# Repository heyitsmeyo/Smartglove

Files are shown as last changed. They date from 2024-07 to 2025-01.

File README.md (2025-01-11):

# Smartglove
The project is about a smart glove that translates ASL (American sign language ) to text and speech using a machine learning model based on random forest algorithms , the model is deployed on a raspberry pi 4 model B  , the glove comes with a esp32 , five fkex sensors and a module that integrates both gyroscope and accelerometer (MPU6050) 

The dataset used in this project can be found here : https://figshare.com/articles/dataset/ASL-Sensor-Dataglove-Dataset_zip/20031017?file=35776586

Screenshot_20240523_001544_Gallery (1)

# PCBDesign : 

pcb

# pcbSchematic :



# if you like the project , you can donate us for more : 

    https://ko-fi.com/heyitsmeyo

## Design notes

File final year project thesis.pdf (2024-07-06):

éJ

J

.ªË@

éJ

£@Q
®Öß

YË@
éK

Q

K@ Qm.

Ì'@
éK

PñêÒm.

Ì'@

Peoples Democratic Republic of Algeria ù

ÒÊªË@ IjJ

Ë@ ð ú

ÍAªË@ Õæ

Êª

JË@
èP@ Pð

Ministry of Higher Education and scientific research

éÓY
®
JÖÏ@ HAJ
k.ñËñ

Jº
JÊË AJ

ÊªË@
éJ

J£ñË@
éPYÖÏ@

National High School of Advanced Technology Department of Electrical Engineering and Industrial Computer Science

### Final Year Project to Obtain the Diploma of

### Engineering

### Field:

### Electronics

### Specialty:

### Embedded Systems

### Subject:

## A Smart Glove Empowered by AI embedded on a Raspberry

Pi

### Realized by

### Benbrahim Tarek

Examination Committee:
Chair | Zellat Khadidja | ENSTA
Supervisor | Bougherirah Hamida USD Blida
Co-Supervisor | Habani Lamia | ENSTA
Examiner | Bouchama Samira | ENSTA
Examiner | Kheira Lakhdari | ENSTA

Algiers, The 26/06/2024

### Academic year 2023 - 2024

Abstract
This thesis presents the development of a smart glove system designed to translate ASL gestures into text and speech. The system uses a combination of flex sensors for finger movement detection, a module that combines accelerometer and a gyroscope for hand gesture capture, and a microcontroller for data processing. Data from all the sensors modules is acquired using an esp32, while the Raspberry Pi 4 is used for executing a machine learning model based on Random Forest algorithms. This model is trained with a dataset to recognize ASL gestures and convert them into text which is then synthesized into speech using a TTS module. That glove aims to help the deaf community to interact easily with the other categories of the society.Initial testings showed successful results,future work will focus on improving the device’s capabilities with other sign languages.
Keywords: machine learning ,microcontroller , Random forest , wireless communication , smart glove , sign language.
R´esum´e:
Cette th`ese pr´esente un gant intelligent traduisant les gestes ASL en texte et parole. Il utilise des capteurs de fl´exions , un acc´el´erom`etre, un gyroscope pour d´etecter les mouvements, et un microcontrˆoleur pour le traitement des donn´ees. Un mod`ele d’apprentissage automatique sur Raspberry Pi 4 reconnaˆıt et convertit les gestes en texte, puis en parole avec un module TTS. Le gant aide la communaut´e sourde `a interagir plus facilement, avec des r´esultats positifs lors des premiers tests. Mots-cl´es: apprentissage automatique, microcontrˆoleur, forˆet al´eatoire, communication sans fil, gant intelligent, langue des signes.

:

jÊÓ

úÍ@

éJ

ºK
QÓ

B@
èPA B
@
é

ªË
éÔg

Q

Ë ÕÔÓ ú

»
X

PA
®
¯ ÐA ¢
QK

ñ¢
ékðQ£

B@ è
Yë ÐY
®
K
èYgðð , ©K.

A

B@
é»Qk á«

ºÊË

é

KQÖÏ@ PAª

B@
è

Qêk.

@ áÓ A

m

'
QÓ ÐA ¢

JË@ ÐY
j
J

.ÐC¿ð

ém

Ì'AªÖÏ

é
®J
¯X Õºm
èYgðð , YJ

Ë@ H@ZAÖ
ß

@

A
®
JËB H.

ñºðQ
m

Ì'@ð ¨PA
Ë@ AJ
®Ó á

K

. ©Òm.

, esp32
èYgð Ð@Y
j
JAK

PAª

B@ H@Ygð ©J
Ôg

áÓ HA
KAJ
J

Ë@ úÎ« ÈñmÌ'@ Õ
æK

.HA
KAJ
J

Ë@

éK

A

ªË@ HAJ
Ó

PP@ñ k úÎ« YÒ
JªK

ú

Í

@ Õ
Îª
K h.
XñÖ

ß
YJ

®

J

JË Raspberry Pi 4 PAêk.

Ð@Y
j

J@ Õ
æK

AÒ
J

K
èPA B
@
é

ªË H@ZAÖ
ß

@
úÎ«

¬Qª
JÊË HA
KAJ
K
é«ñÒm.

× Ð@Y
j
JAK
. h.

XñÒ

JË@ @
Yë I.

K

PY
K Õ
æK

éJ

K@ñªË@

úÍ@

JË@ ÉK
ñm
èYgð Ð@Y
j
JAK

ÐC¿ úÍ@
½Ë
X YªK

é

®J

Ëñ
K Õ
æK

úÍ@
AêÊK

ñm

ð
éJ

ºK
QÓ

B@

áÓ øQ

k

B@ HA
J

®Ë@ ©Ó
éËñîD. É«A
®

JË@ úÎ« ÕæË@ ©Ò
Jm

×

èY«AÓ úÍ@
PA
®
®Ë@ @
Yë

¬YîE

.ÐC¿

á

m

úÎ«
ú

ÎJ
®
JÖÏ@ ÉÒªË@ Q»Q
ð ,
émk

A
K l .
A
J

K

éJ

Ëð

B@ H@PAJ
J

kB@ HQê

£

@ Y
¯ð , ©Ò
Jj.

ÖÏ@

.øQ

k

B@
èPA B

@ HA
ªË ©Ó PAêm.

Ì'@ H@PY

¯

HBA

B@ ,
éJ

K@ñªË@

éK

A

ªË@ HAJ
Ó

PP@ñ k ,

J
¯YË@ Õºj

JÖÏ@ ,
éË
B@ ÕÎª
K :
éJ

kA
J

®ÖÏ@ HAÒÊ¾Ë@

èPA B
@
é

ªË , ú

»
YË@ PA
®

®Ë@ ,
éJ

ºÊCË@

# Acknowledgments

### I would like to extend our heartfelt gratitude to the Almighty God, the All-Powerful and Merciful, who gave us the strength and dedication to

complete this work.

### I deeply appreciate the guidance and dedication of my co-supervisor Mme.Habani and my supervisor Mme.Bougherira, who generously

shared their expertise, time, and effort towards achieving this great work.

### Many thanks to the jury members for their interest in our work and

their willingness to evaluate it.

### I am also grateful to my family members, whose unwavering support and assistance have been instrumental in my journey towards the com-

pletion of this endeavor.

# Dedication

These first words are dedicated to my beloved parents , my mother , my father. These words are full of deep feelings that i wanna write for you , you both gave me support , energy and the zeal to be what I am now.

My mother , your priceless contribution to me is what I can’t forget , your words , your sacrifices to create the current version of me are unforgettable , May Allah bless you and keep you safe for our family , your absence is what i can’t think about.

The father , the power of your words tell the amount of wisdom you have , your strength , your confidence taught me a lot to face this life tall and to never think about giving up. May Allah bless you too.

Other feelings expressed to my sisters , my little brother , your company is and still a priceless journey.

To my dear friends , getting to know you wasn’t a coincidence , it was a lesson , a historical event that i can’t lose off my memories , May Allah keep us together and forever

# Table of contents

1 State of the Art | 2
2 Embedded sign language to speech synthesizer design | 16

I

3 Results and implementation of the smart glove | 29

II

# List of Figures

1.1 Hadeel Ayoub | | 4
1.2 Brightsign smart glove | | 4
1.3 supervised learning | | 4
1.4 unsupervised learning | | 4
1.5 Neural Network | | 5
1.6 Support Vector Machine | | 6
1.7 Random Forest | | 6
1.8 Sign language common words | | 7
1.9 American sign language alphabet | | 7
1.10 Raspberry Pi & Arduino Uno | | 8
1.11 Raspberry pi 4 model B | | 9
1.12 Raspberry pi 4 model B Pinout | | 9
1.13 ESP32 Wroom S3 | | 10
1.14 Esp32 Wroom S3 pinout | | 11
1.15 flex sensor 2.2 inch | | 11
1.16 MPU6050 (accelerometer & gyroscope) | | 12
1.17 STREAM System | | 13
1.18 Algeria-Korea partnership certificate | | 13
1.19 PCB Production uni | | 14
1.20 PCB Production uni | | 14
1.21 PCB Production uni | | 14
1.22 PCB Production uni | | 14
2.1 System block diagram | | 17
2.2 Functional flowchart | | 18
2.3 Flex sensor functionality | | 19
2.4 Different bending angles of flex sensor | | 19
2.5 Flex sensor wiring system | | 20
2.6 Flex sensor’s Polarities | | 20
2.7 Wiring Diagram of Flex Sensors to ESP32 | | 20
2.8 Flex sensors wiring schematic | | 20

III

2.9 MPU6050 Axis | | 21
2.10 Wiring Diagram of MPU6050 to ESP32 | | 21
2.11 Esp32-Raspberry pi 4 wireless communication diagram | | 22
2.12 Voting Mechanism in Ensemble Learning for Prediction | | 24
2.13 Random Subset Selection and Classification with Decision Trees . . . . | 24
2.14 Bootstrapping and Aggregation in Random Forests | | 24
2.15 Random forests data bootstrapping | | 24
2.16 Enter Caption | | 26
3.1 Google Colab | | 30
3.2 EasyEda | | 31
3.3 Raspberry pi 4 Linux Desktop | | 32
3.4 RealVnc Viewer | | 32
3.5 Smart glove’s Schematic | | 33
3.6 EasyEda PCB Design | | 34
3.7 PCB Design result | | 34
3.8 3D Top view of Double-Sided PCB Prototype | | 35
3.9 3D bottom View of Double-Sided PCB Prototype | | 35
3.10 UV Exposure After Applying Solder Mask | | 36
3.11 Top View of Double-Sided PCB Prototype | | 36
3.12 Bottom View of Double-Sided PCB Prototype | | 36
3.13 Smart Glove | | | 37
3.14 Flex sensors Calibration code | | 38
3.15 Flex sensors calibration results | | 39
3.16 MPU6050 Calibration process | | 39
3.17 ESP32 WI-Fi connection code | | 40
3.18 Sensors data processing code | | | 40
3.19 Python Code for data reception | | 41
3.20 Sensors data reception results | | 41
3.21 Machine learning Training Process | | 42
3.22 Python code for merging dataset | | 43
3.23 Python code for cleaning dataset | | 43
3.24 Python code for eliminating unnecessary dataset | | 43
3.25 Python code for data normalisation | | 45
3.26 Python Code for Splitting Dataset into Training and Testing Sets . . . | 45
3.27 Random forests classifier python code | | 45
3.28 Python code for generating predictions on Test data | | | 46
3.29 Alphabet Sign language Confusion Matrix (99% model accuracy) . . . | 47
3.30 Sign language expressions Confusion Matrix(98% model accuracy) . . . | 48

IV

3.31 Testing and training accuracy for different number of trees (99% model
accuracy) | | 49
3.32 OOB Score for different number of trees(99% model accuracy) | | 49
3.33 Alphabet sign language ROC curve(99% model accuracy) | | 50
3.34 Alphabet Sign language Confusion Matrix (82% accuracy) | | 52
3.35 Alphabet sign language ROC curve(82% accuracy) | | 53
3.36 Testing and training accuracy for different number of trees(82% accuracy) 54
3.37 OOB Score for different number of trees(82% model accuracy) | | 54
3.38 Enter Caption | | 55
3.39 Testing and training accuracy with classifier’s changed parameters . . . | 57
3.40 Testing and training accuracy with classifier’s default parameters . . . | 57
3.41 letter A in sign language | | 58
3.42 correlation plot of the letter A | | | 58
3.43 letter S in sign language | | 58
3.44 correlation plot of the letter S | | 58
3.45 Decision Tree plot (82% accuracy) | | 59
3.46 Decision Tree plot (99% accuracy | | 60
3.47 Python Code for Dumping machine learning model | | 64
3.48 Python Code for loading machine learning model | | 64

V

# List of Tables

1.1 Literrature survey | | 3
1.2 Raspberry pi Vs Arduino Uno | | | 8
2.1 Dataset sample | | 27
3.1 Dataset pre-processing results | | 44
3.2 sign language expressions Classification report | | 62
3.3 sign language alphabet Classification report | | 63

VI

# List of Abbreviations

1. ADC: Analog to Digital Converter
2. ANN: Artificial Neural Network
3. AUC: Area under the ROC Curve
4. ASL: American Sign Language
5. IDE: Integrated Development Environment
6. I2C: Inter-Integrated Circuit
7. OOB: Out Of Bag
8. PCB: Printed Circuit Board
9. RF: Random Forest
10. ROC: Receiver Operating Characteristic
11. SVM: Support Vector Machine
12. TN: True Negative
13. TP: True Positive
14. VNC: Virtual Network Computing

VII

## General Introduction

The ability to communicate effectively is fundamental to human interaction. However, for individuals who are deaf, spoken language and written text may not be accessible.ASL is a visual language used by many in the deaf community, but its understanding and interpretation by those who are unfamiliar with it can be a challenge. This issue shows the importance of finding new solutions.Motivated by this need, our project consists of the development of a smart glove system designed to translate ASL gestures into text and speech. The smart glove integrates a combination of flex sensors and accelerometers to detect and interpret hand movements, along with a microcontroller for data processing. A machine learning model based on Random Forest algorithms is trained with a dataset to recognize ASL gestures and convert them into text. The text is then synthesized into speech using a text-to-speech (TTS) module, providing a

comprehensive communication solution.
The smart glove is designed to improve communication between deaf and hearing communities by providing a more accessible and inclusive way to communicate.
The thesis consists of three chapters. The first chapter covers the current state of the art, smart gloves development, proposed approach, required material, machine learning algorithms, and why random forest was chosen. It also mentions briefly the internship journey. The second chapter explains how the glove was embedded, including components wiring , machine learning algorithm details including its hyper-parameters, and dataset pre-processing. The last chapter discusses the tests and results of the model training.

# Chapter 1

# State of the Art

CHAPTER 1. STATE OF THE ART

## 1.1 Introduction

This chapter provides an overview of the current state-of-the-art in smart glove technology for communication with deaf or hard-of-hearing individuals. The following sections will explore the technical details of existing systems, including hardware and software components

## 1.2 Literature Survey

The Table 1.1 below shows the existing literature on smart gloves and their applications in various fields.
Authors | System Description | Technology | Accuracy | Sign Language
Jagannath N., Manasa V., T. V. Prasad | Designed a smart glove using IoT technology for capturing and translating hand gestures [1] . | Flex sensors, accelerometer, gyroscope, Wi-Fi or GSM for data transmission, hap-tic feedback, speech output | 85% | Indian Sign Language
Muhammad Rifki Kur-niawan, Ahmad Hasibul Hadi, Siska Novitasari | Developed a smart glove to trans-late sign language into text or speech, processed by an Arduino board and transmitted via Blue-tooth [2]. | Flex sensors, accelerometer, gyro-scope, Bluetooth | 91.7% | Indonesian Sign Language
S. Sruthi, R. Sivaran-jani, S. Sathya | Presented a smart glove using sen-sor fusion techniques to improve gesture recognition accuracy, in-cluding a speech recognition mod-ule [3]. | Flex sensors, accelerometer, gy-roscope, magnetometer, Arduino board, fusion algorithm | 97.5% | Not specified
Neven Saleh, Mostafa Farghaly, Eslam Elshaaer | Developed a low-cost smart glove system to recognize hand gestures in Arabic sign language [4]. | Flex sensors, triaxial MEMS mod-ule (MPU-6050), Android applica-tion | 90% | Arabic Sign Language
Sawant Pramada, Archana Suhas Vaidya | iscussed developing an algorithm to accurately detect the number of fingers opened in a gesture repre-senting an alphabet in Binary Sign Language [5]. | Algorithm development for gesture recognition | Not specified | Binary Sign Language

Table 1.1: Literrature survey

One of The most advanced smart gloves in the world was created by Hadeel Ayoub,

CHAPTER 1. STATE OF THE ART

a 37-year-old Saudi Arabian woman. She is a London-based designer, programmer, and researcher in human-computer interaction. This glove, the first of its kind, assists deaf individuals without speech ability to communicate using any sign language they prefer. It offers the flexibility to select from 40 different spoken languages.[6].

Figure 1.1: Hadeel Ayoub | Figure 1.2: Brightsign smart glove

## 1.3 Machine learning

Our project is mainly based on machine learning with AI , hence let’s have a brief talk about 3 algorithms : NN (Neural Network) , RF ( Random Forest ) and SVM (Support Vector Machine) , the three of them are related to supervised learning which is a type of machine learning where the model is trained on a labeled dataset[7]. In supervised

learning, each training example in the dataset consists of inputs and a corresponding output. The goal of supervised learning is to learn a mapping from inputs to outputs, so that the model can make predictions or decisions when given new, unseen data. These details are illustrated in Figure 1.3

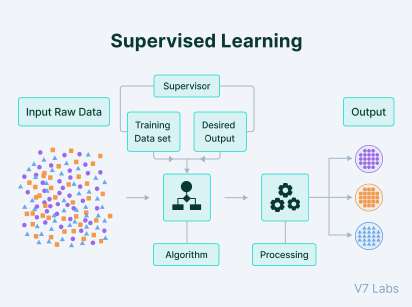
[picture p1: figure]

Figure 1.3: supervised learning | Figure 1.4: unsupervised learning

CHAPTER 1. STATE OF THE ART

On the other side and as shown in Figure 1.4 , we have unsupervised learning, which is also a type of machine learning that does not need any target labeled to be specified, it just regroups patterns, and all similar dataset, it is really helpful when dealing with quite large datasets.We can find many algorithms developed for this type of learning like K-means , DBSCAN and Hierechial clustering.[8].

1. ANN: A neural network is a type of machine learning model that emulates the decision-making process of the human brain. This is achieved by simulating the interconnected behavior of biological neurons, enabling them to recognize patterns, evaluate choices, and make decisions. Each neural network comprises layers of nodes, or artificial neurons, including an input layer, one or more hidden layers,(See Figure 1.5) and an output layer. Nodes are interconnected, each with

its own weight and threshold. When the output of a node exceeds its threshold, it activates and transmits data to the next layer. Otherwise, the data is not forwarded to the subsequent layer.[9].

Figure 1.5: Neural Network

2. SVM (Support Vector Machine): The Support Vector Machine (SVM) is a

supervised machine learning algorithm used for both classification and regression tasks, although it is particularly well-suited for classification. Its primary goal is to identify the optimal hyperplane within an N-dimensional space that effectively separates data points into different classes in the feature space[10]. The algorithm

CHAPTER 1. STATE OF THE ART

aims to maximize the margin between the closest points of different classes as see in Figure 1.6, with the dimension of the hyperplane determined by the number of features. For instance, in the case of two input features, the hyperplane is a line, while with three input features, it becomes a 2-D plane. However, visualizing the hyperplane becomes challenging as the number of features exceeds three.

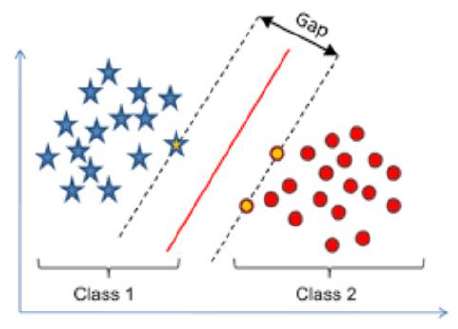
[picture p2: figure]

Figure 1.6: Support Vector Machine

3. Random Forests classification: Random Forest is an ensemble of Decision Trees whereby the final/leaf node will be either the majority class for classification problems or the average for regression problems. A random forest will grow many classification trees and for each output from that tree, we say the tree ‘votes’ for that class as shown in Figure 1.7.[11].

Figure 1.7: Random Forest

CHAPTER 1. STATE OF THE ART

## 1.4 Embedded platforms

### 1.4.1 Propsed methodology

This study aims to develop a smart glove system that translates American Sign Language (ASL) gestures into text and speech. The system will utilize five flex sensors

to detect finger movements and a module integrating an accelerometer and gyroscope (MPU6050 module) to capture hand gestures, all integrated into the glove. An ESP32

will be used for data acquisition from the flex sensors and MPU6050, transmitting the collected data to a Raspberry Pi 4 via Wi-Fi. The Raspberry Pi 4 will handle more advanced data processing tasks. An AI model based on Random Forest algorithms will be trained using the sensors data to recognize ASL gestures and convert them into text, which will then be synthesized into speech. The Figure 1.8 and Figure 1.9 show different American sign language expressions and alphabet.

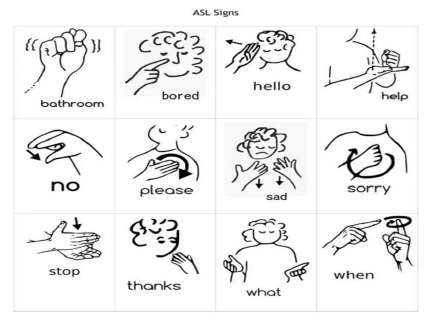
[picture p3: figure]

Figure 1.8: Sign language common words Figure 1.9: American sign language alphabet

### 1.4.2 Raspberry pi 4 over Arduino

According to literature survey, smart gloves have been developed using Raspberry Pi and Arduino. The focus of our approach is primarily on Raspberry Pi, specifically the Raspberry Pi 4 Model B. We chose it because it is well-suited for training machine learning models,Additionally, Raspberry Pi provides advantages in terms of processing power and connectivity when compared to Arduino. The table 1.2 provided below summarizes the key reasons for choosing Raspberry Pi over Arduino for our project.

CHAPTER 1. STATE OF THE ART

Figure 1.10: Raspberry Pi & Arduino Uno

Feature | Raspberry Pi 4 Model B (4GB RAM) | Arduino
Processor | Quad-core Cortex-A72 (ARM v8) 64-bit SoC @ 1.5GHz | Varies by model (e.g., ATmega328P on Uno)
RAM | 4GB LPDDR4 | None (memory is onboard the microcontroller)
Storage | MicroSD slot for loading OS and data storage | No onboard storage, uses external EEPROM
Operating System | Runs full Linux distributions (e.g., Raspbian) | No OS, runs simple firmware
Connectivity | Gigabit Ethernet, Wi-Fi 802.11ac, Bluetooth 5.0 | Limited (usually requires external modules)
USB Ports | 2 x USB 3.0, 2 x USB 2.0 | Typically none or limited
GPIO Pins | 40-pin header | Varies by model (e.g., 14 digital, 6 analog on Uno)
Video Output | 2 x micro-HDMI ports, supports dual 4K monitors | None
Power Supply | 5V via USB-C or GPIO header | Varies (e.g., USB or barrel jack)
Development Environment | Supports various IDEs, programming languages | Arduino IDE, C/C++
Typical Use Cases | Full-fledged computer, media center, server, IoT | Embedded systems, simple robotics, IoT
Cost | Generally higher than Arduino | Generally lower than Raspberry Pi

Table 1.2: Raspberry pi Vs Arduino Uno

CHAPTER 1. STATE OF THE ART

Now, let us see the list of materials needed to realize the project:

Raspberry pi 4 model B : The Raspberry Pi 4 is a popular single-board computer (SBC) developed by the Raspberry Pi Foundation as shown in Figure 1.11. It

is the fourth generation of the Raspberry Pi series and offers improved performance and features compared to its predecessors[12]. The model B has:

Figure 1.11: Raspberry pi 4 model B

Figure 1.12: Raspberry pi 4 model B Pinout

1. Processor: Quad-core ARM Cortex-A72 (64-bit) processor running at 1.5GHz.
2. Memory: Options for 2GB, 4GB, or 8GB of LPDDR4 RAM.

CHAPTER 1. STATE OF THE ART

3. Connectivity: Dual-band 802.11ac wireless networking (Wi-Fi), Bluetooth 5.0,

Gigabit Ethernet, and USB 3.0 ports.

4. Video Output: Dual micro-HDMI ports supporting up to 4K resolution.
5. GPIO: 40-pin GPIO header for connecting external devices and components.
6. Storage: MicroSD card slot for operating system and data storage.
7. Power: USB-C power port for powering the device.

Esp32 Wroom S3 : The Figure 1.13 shows an ESP32 which is a microcontroller manufactured by Espressif Systems, featuring the ESP32 chip with integrated WiFi and Bluetooth. The microcontroller boasts a dual-core processor utilizing the Xtensa LX7 architecture, operating at a clock speed of 240 MHz and equipped with 4Mb of memory[13]. Its sixteen 12 bits adc channel and ability to communicate with other

boards wirelessly make it the better choice for our project as the board has:

1. Processor: Dual-core Xtensa® LX7 microcontroller, operating at up to 240 MHz.
2. RAM: 512 KB internal SRAM.
3. ROM: 384 KB of ROM for bootloader, security functions, and library functions.
4. Flash: Typically 4 MB (external), used for program storage.
5. Cache: 16 KB of instruction cache and 8 KB of data cache.

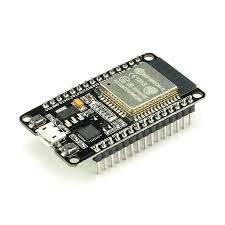
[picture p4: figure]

Figure 1.13: ESP32 Wroom S3

CHAPTER 1. STATE OF THE ART

Figure 1.14: Esp32 Wroom S3 pinout

flex sensor 2.2 sen-10264: Flex sensor 2.2” (SEN-10264) is a type of bend sensor that changes its resistance (25K Ohms ±30%)based on the degree of bending.

It is 2.2 inches (56mm) in length and is typically used to detect the bending of fingers or other objects.[14].

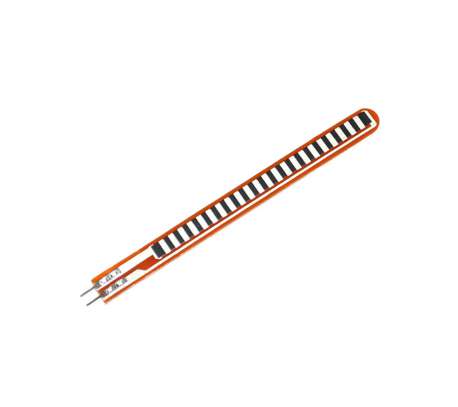
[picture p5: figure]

Figure 1.15: flex sensor 2.2 inch

MPU6050 Module: the MPU6050 sensor module is a complete 6-axis motion tracking device. It combines 3-axis Gyroscope, 3-axis accelerometer and Digital Motion Processor all in small package. Also, it has additional feature of an on-chip Temperature sensor. It has I2C bus interface to communicate with the microcontrollers.[15]. This

module is used to detect hand gesture movement and orientation.

CHAPTER 1. STATE OF THE ART

Figure 1.16: MPU6050 (accelerometer & gyroscope)

As mentioned in section 1.4.1 that in our thesis , Random Forest algorithms were chosen and that’s for the following reasons:

1. Over-fitting : comparing to NN and SVM , Random forests deals with the problem of overfitting by creating multiple trees, with each tree trained slightly differently so it overfits differently.This makes random forest very robust to overfitting and able to handle complex relationships between the features and the target variable.[16].
2. High and stable accuracy: Random Forest’s high accuracy stems from its ability to handle both classification and regression tasks effectively. It can handle large datasets with high dimensionality and is less prone to overfitting compared to individual decision trees.[17].
3. Less training time : Random Forests can be parallelized, allowing the individual decision trees to be trained simultaneously on different subsets of the data. This parallelization can significantly reduce the overall training time, especially on multi-core or distributed computing systems.[18].
4. Ability to estimate missing data: Random Forests have the ability to estimate missing data, making them a useful choice for datasets with incomplete information. When training a Random Forest model, missing values in the dataset do not need to be imputed or filled in beforehand, as the algorithm can handle missing data internally during the training process.[19].

Random Forest algorithms often provide excellent results when working with tabular datasets. Tabular datasets are structured data organized into rows and columns,

CHAPTER 1. STATE OF THE ART

where each column represents a feature or attribute, and each row represents an individual data point or observation[20].They are well-suited for tabular data because they

can handle a mix of categorical and numerical features which is the case of the used dataset.

## 1.5 Internship experience at STREAM

In addition to the theoretical exploration , the internship has been for a month in STREAM which is an algerian company that manufactures electronic devices such as smart phones and televisions , it has the leadership in the country with exportation to different european countries including Germany and France. I have been in Bomare company which is a affiliate. There are three departments :

Figure 1.17: STREAM System | Figure 1.18: Algeria-Korea partnership cer- tificate

### 1.5.1 Assembling Unit

in this unit , the product is ready , it just needs to be covered up and sold to the clients.

### 1.5.2 PCB Production unit

the PCBs are imported from China , all they do is soldering electronic components into the board with specific machines and that includes soldering , and then physical inspection of the produced boards.

### 1.5.3 Repairing Unit

they do repair all clients electronic devices , there is also another department that takes in charge the industrial project development

CHAPTER 1. STATE OF THE ART

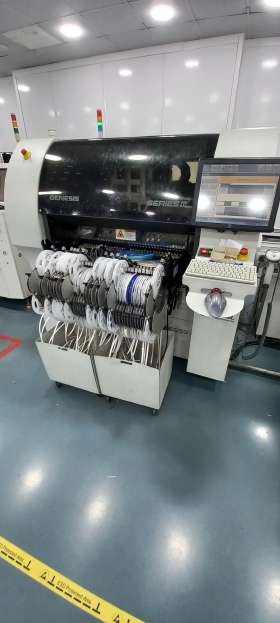
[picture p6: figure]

Figure 1.19: PCB Production uni | Figure 1.20: PCB Production uni
Figure 1.21: PCB Production uni | Figure 1.22: PCB Production uni

CHAPTER 1. STATE OF THE ART

## 1.6 Conclusion

In conclusion, the first chapter of our thesis has provided a comprehensive overview of our research topic, focusing on the development of a smart glove for American Sign Language (ASL) translation.Additionally, we talked briefly about the proposed

methodology, including the algorithms and components that will be used. The next chapter would give bright details concerning the methodology and and sign language to speech synthesizer design.

# Chapter 2

# Embedded sign language to speech

# synthesizer design

CHAPTER 2. EMBEDDED SIGN LANGUAGE TO SPEECH SYNTHESIZER DESIGN

## 2.1 Introduction

In this chapter, we will provide further details about the approach used in developing this project, including specifics about the software and hardware used.

## 2.2 System block diagram and flowchart

The Figure 2.1 shows a ”Smart Glove System” created to convert sign language into text and speech, improving communication for people with hearing impairments. The glove has five flex sensors to detect finger movements, and an MPU6050 sensor records the hand’s position and movements. These sensors transfer information to the ESP32 Wroom S3 microcontroller and then , the microcontroller processes the data and sends it wirelessly to a Raspberry Pi 4 Model B that contains a machine learning model which interprets the sign language gestures , the system changes the sign language into text and then into speech, which are both displayed and heard audibly. The Figure 2.2 represents the functional flowchart of the system.

Figure 2.1: System block diagram

CHAPTER 2. EMBEDDED SIGN LANGUAGE TO SPEECH SYNTHESIZER DESIGN

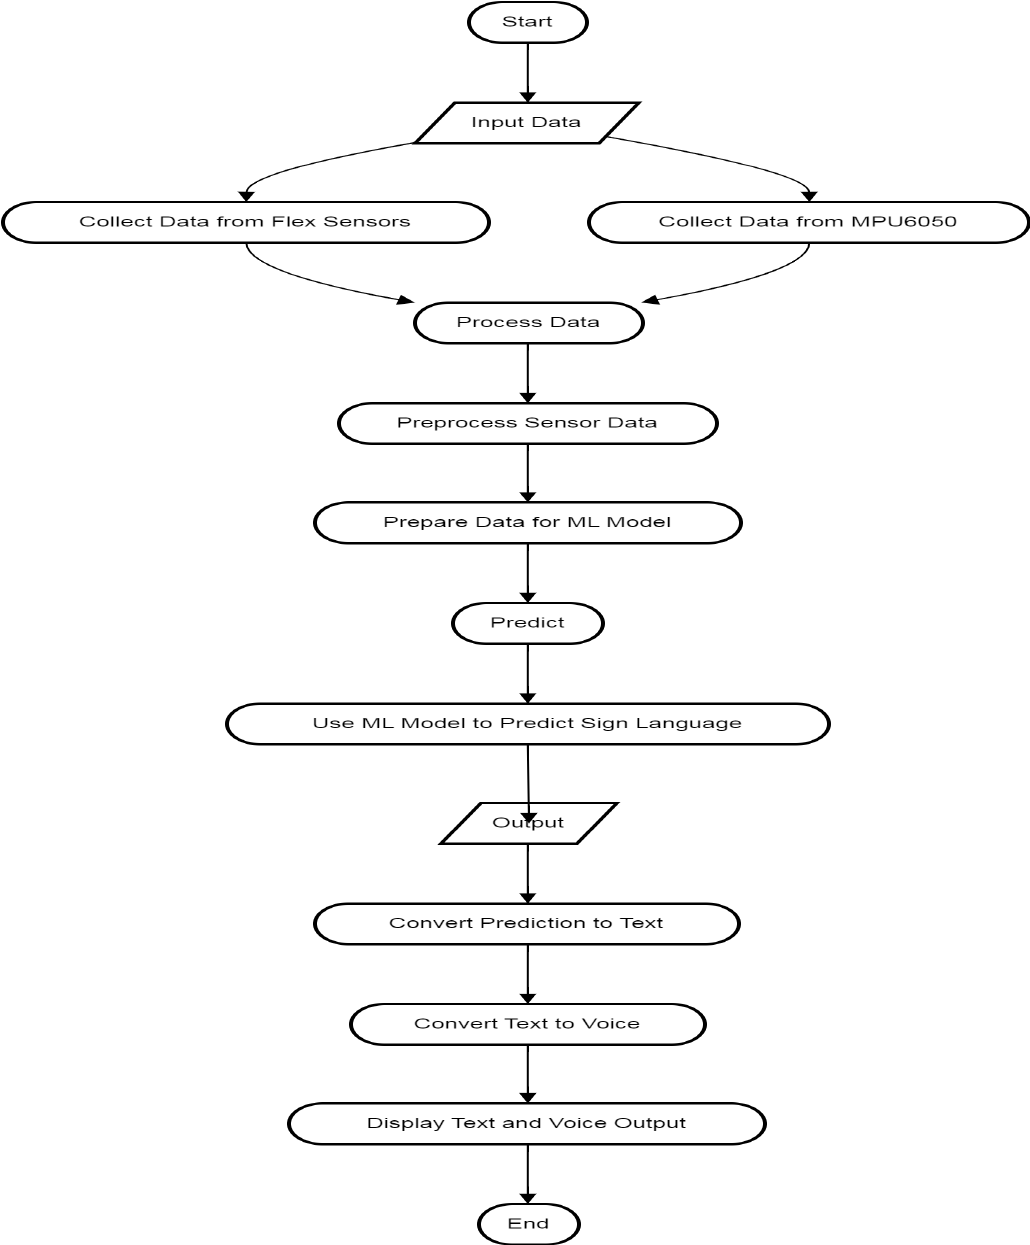
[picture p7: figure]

Figure 2.2: Functional flowchart

CHAPTER 2. EMBEDDED SIGN LANGUAGE TO SPEECH SYNTHESIZER DESIGN

## 2.3 Hardware assembling

Our project is based on flex sensors and the MPU6050 module. The first ones are connected to the esp32’s ADC channels since the board has 16 ADC channels. This setup was opted for because the Raspberry Pi 4 lacks ADC channels, whereas the MPU6050 is connected to the I2C pins of the microcontroller.

### 2.3.1 Flex sensors

we talked briefly about the flex sensors that they are variable resistors that change when bending , the value of its resistance when it’s flat (0°) is approximately 25KΩ and about 100kΩ when it’s 90°.[21].

Figure 2.3: Flex sensor functionality Figure 2.4: Different bending angles of flex sensor

Flex sensors Wiring to ESP32 : The flex sensor has two inputs named p1 and p2, where p2 is connected to 5v and p1 is connected to a resistor that is then connected to ground (pull down resistor). The resistor is added to create a voltage divider, allowing the voltage to change based on the flex bending. Another pin between the resistor and p2 is connected to one of the Arduino’s ADC channels so it would be possible to read the analog value. In our case , we use five flex sensors , and the value of the resistors are all the same (10KΩ) Theoretically, the voltage on the resistor can

be calculated using the voltage divider theorem. Considering the added resistor as R2, the flex sensor as R1, and the target voltage as V:

V =

R1
R2 + R1
× 5 | (2.1)

when the sensor is flat : R1 = 10KΩ , R2 = 32,5KΩ

V =

R1
R2 + R1
× 5 = 1.17V | (2.2)

CHAPTER 2. EMBEDDED SIGN LANGUAGE TO SPEECH SYNTHESIZER DESIGN

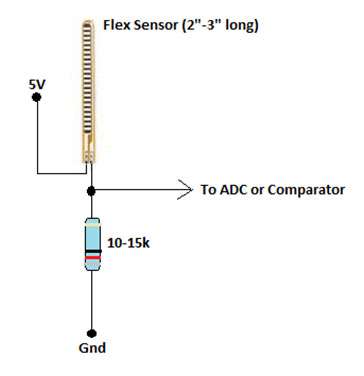
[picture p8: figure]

Figure 2.5: Flex sensor wiring system | Figure 2.6: Flex sensor’s Polarities

Figure 2.7: Wiring Diagram of Flex Sensors to ESP32

Figure 2.8: Flex sensors wiring schematic

### 2.3.2 MPU6050

### The MPU6050 module simultaneously calculates acceleration and rota-

### tion for all three axes (x, y, and z) with a three-axis accelerometer and a

### three-axis gyroscope. Acceleration is determined by sensing the deflec-

tion of a small mass within the sensor when subjected to acceleration,

### utilizing capacitance variation principles. Electrodes inside the sensor

### measure capacitance changes due to mass deflection, enabling the sensor

to ascertain acceleration along each axis.[22].

CHAPTER 2. EMBEDDED SIGN LANGUAGE TO SPEECH SYNTHESIZER DESIGN

### Regarding rotation, the gyroscope operates based on the Coriolis ef-

### fect. A small vibrating element inside the gyroscope deflects perpendic-

### ular to the rotation direction due to the Coriolis force when the sensor

### rotates. This deflection is directly linked to the angular rate of rota-

### tion. By measuring the vibrating element’s deflection, the sensor can

determine the rate of rotation around each axis.[22].

### The reason for choosing MPU6050 is due to the sign language ex-

### pressions and the two alphabet(J & Z) that require both movement and

rotation of the hand.

Figure 2.9: MPU6050 Axis

### MPU6060 wiring to ESP32 : The module is connected directly

### to the esp32 via I2C communication , the two pins SDA and SCL are

connected to the I2C pins ( GPIO21 for SDA and GPIO22 for SCL).

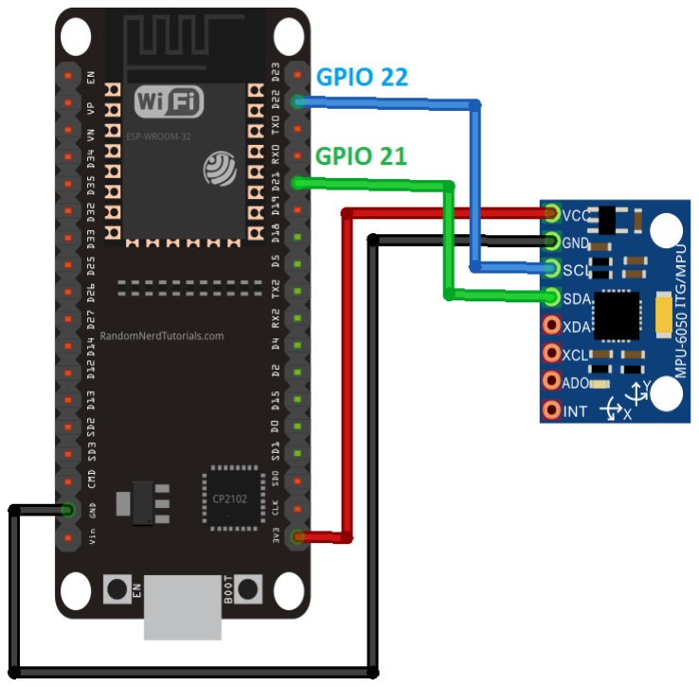
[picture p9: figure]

Figure 2.10: Wiring Diagram of MPU6050 to ESP32

CHAPTER 2. EMBEDDED SIGN LANGUAGE TO SPEECH SYNTHESIZER DESIGN

## 2.4 Esp32 wireless communication with raspberry

pi

### The esp32 sends the sensors data to the raspberry pi 4 via Wi-Fi with

### TCP/IP protocol.The Raspberry Pi 4 running a TCP/IP server listens

### for incoming sensor data packets from the ESP32 over the Wi-Fi net-

### work[23]. Once the data is received, the Raspberry Pi processes and

analyzes it.

Figure 2.11: Esp32-Raspberry pi 4 wireless communication diagram

## 2.5 Random forest classifier

### As already mentioned that the data processing in the project is based

### on random forest algorithms , there are two types : the classifier and the

### regressor , in our case , we intend to work with the classifier since we

### want to predict an alphabet on the output as each alphabet or expression

represents a class.

CHAPTER 2. EMBEDDED SIGN LANGUAGE TO SPEECH SYNTHESIZER DESIGN

### 2.5.1 Description of the classifier

### Given a dataset with N samples , random forest creates many subsets

### called bootstrap samples ,trains a decision tree on each bootstrap sample

, after growing trees and for classification, each tree ”votes” for a class,

### and the class with the most votes is predicted by the random forest

### algorithm. the final step is aggregation which is the process of combining

### multiple individual predictions or results into a single, final prediction

or result.[18]. The description is more illustrated in the Figures 2.12 ,

2.13 , 2.14 , 2.15

### This classifier has different parameters that have a crucial imapct on

### the model’s performaces:

### 1. Number of estimators : the estimators are simply the trees , many

trees make a forest , the number of trees can play a huge impact , the more they are , the good the model is.[24].

### 2. max depth: this parameter represents the maximum height the trees

can reach within the forest,[24].

### 3. minimum samples split: it controls the number of samples needed

### to split internal tree nodes by limiting its growth to avoid overfit-

ting.[24].

### 4. minimum samples leaf:this is the minimum number of samples that

a node must hold after getting split.[24].

### 5. maxleaf nodes: it sets the maximum number of leaf nodes in the

### tree , this also can help preventing overfitting as the model will

### stop growing nodes whenever it reaches the maximum number of

leaf nodes.[24].

### 6. Random state : The random state is used to shuffle the data before

splitting it into a training set.[24].

CHAPTER 2. EMBEDDED SIGN LANGUAGE TO SPEECH SYNTHESIZER DESIGN

Figure 2.12: Voting Mechanism in Ensemble Learning for Prediction

Figure 2.13: Random Subset Selection and Classification with Decision Trees

Figure 2.14: Bootstrapping and Aggregation in Random Forests

Figure 2.15: Random forests data bootstrapping

## 2.6 Validation and evaluation methods

### 2.6.1 OOB score

### Out of bag is a method of validating a random forests model’s prediction

### error as it consists of the dataset entries that were neglected and not

CHAPTER 2. EMBEDDED SIGN LANGUAGE TO SPEECH SYNTHESIZER DESIGN

### trained by the machine learning algorithm. This method provides a

good idea about the model’s performances on unseen data.[25].

### OOB Score = 1

n

X

n

i=1

### I(yi = ˆy

OOB
i
) | (2.3)

### 2.6.2 Accuracy

### The accuracy of a machine learning model represents the number of

correct predictions among the total of them.[26].

### Accuracy = Number of correct predictions

Total number of predictions | (2.4)

### 2.6.3 Precision

### Tt’s the number of true positive predictions among the the number of

### correct ones , it becomes very crucial if the model is trained to predict

both negative and positive values.[27].

Precision = | True Positives
True Positives + False Positives | (2.5)

### 2.6.4 ROC-AUC

### Tt gives information about how the model can distinguish between classes.The

ROC-AUC score ranges from 0 to 1.[28].

### ROC-AUC = Z 1

0

TPR(F P R) d(FPR) | (2.6)

### 2.6.5 Features importance

### The importance of features gives us a better understanding of the most

influential features that were used during the training of the model.[11].

### 2.6.6 Confusion matrix

### it’s a table that shows both true and predicted different classes, it can

### help visualize the model performances and how each classes is getting

CHAPTER 2. EMBEDDED SIGN LANGUAGE TO SPEECH SYNTHESIZER DESIGN

### trained[29]. , here is an example :

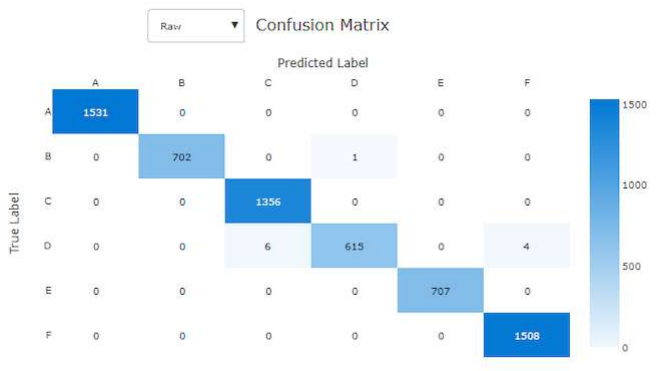
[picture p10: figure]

Figure 2.16: Enter Caption

### 2.6.7 F1-score

### The F1 score can be interpreted as a harmonic mean of the precision

### and recall, where an F1 score reaches its best value at 1 and worst score

### at 0. The relative contribution of precision and recall to the F1 score

### are equal[30]. The formula for the F1 score is:

F1 = 2 ×

### Precision × Recall

Precision + Recall | (2.7)

### 2.6.8 Correlation matrix

### The correlation matrix is a matrix that shows the correlation between

### variables. It gives the correlation between all the possible pairs of values

in a matrix format.[31]. The correlation coefficient is denoted by “r”,

and it ranges from -1 to 1.

1. If r = -1, it means that there is a perfect negative correlation.

### 2. If r = 0, it means that there is no correlation between the two

variables.

CHAPTER 2. EMBEDDED SIGN LANGUAGE TO SPEECH SYNTHESIZER DESIGN

3. If r = 1, it means that there is a perfect positive correlation.[32].

## 2.7 Training dataset

### 2.7.1 Description

### The dataset used in this project isn’t ours, but we could find one that

### contains 40 ASL including 26 alphabet and 14 expressions collected from

### 24 volunteers as each one of them trained the 40 ASL[33] , 1500 entries

### for each sign language. Here’s an sample from the dataset of the letter

### A as seen on the Table 2.1

timestamp | user id | flex 1 | flex 2 | flex 3 | flex 4 | flex 5 | Qw | Qx | Qy | Qz | GY Rx | GY Ry | GY Rz | ACCx | ACCy | ACCz | ACCx body | ACCy body | ACCz body
1616133208.5124247 | 001 | 20.0 | 58.0 | 72.0 | 77.0 | 58.0 | 0.773499 | 0.087097 | -0.627747 | 0.002014 | -0.068702 | -0.015267 | 0.015267 | 9.314306 | 1.379321 | 1.770508 | -0.205762 | 0.082544 | -0.155518
1616133208.5224576 | 001 | 20.0 | 58.0 | 70.0 | 76.0 | 58.0 | 0.773438 | 0.08606 | -0.627991 | 0.001587 | -0.076336 | -0.015267 | 0.022901 | 9.29038 | 1.372144 | 1.762134 | -0.23208 | 0.086133 | -0.162695
1616133208.5324895 | 001 | 20.0 | 58.0 | 73.0 | 75.0 | 60.0 | 0.773376 | 0.0849 | -0.628235 | 0.001099 | -0.076336 | -0.022901 | 0.022901 | 9.301147 | 1.34104 | 1.754956 | -0.22251 | 0.066992 | -0.16748
1616133208.5422645 | 001 | 19.0 | 58.0 | 73.0 | 79.0 | 58.0 | 0.773254 | 0.083679 | -0.62854 | 0.000732 | -0.076336 | -0.022901 | 0.022901 | 9.331055 | 1.271655 | 1.739404 | -0.194995 | 0.011963 | -0.179443

Table 2.1: Dataset sample

### 2.7.2 Dataset pre-processing

### This dataset sample has different ”features”. In terms of important ones

### , there are a total of 11: five from the flex sensors data and six derived

### from the MPU6050 (3-axis accelerometer, 3-axis gyroscope). for the flex

### sensors , the data are the angles of bending not the analog values as a

### consequence , these analog values need to be converted to angles. Our

### aim is to train the model to predict all 26 alphabets and 14 expressions:

you, good, no, yes, hungry, deaf, please, sorry, thank you, hello, me,

### bad, fine, goodbye , but before adding a step to the training process

,The dataset should be cleaned as it may contain noise or missing data,

### which includes:

1. Deleting duplicates.

CHAPTER 2. EMBEDDED SIGN LANGUAGE TO SPEECH SYNTHESIZER DESIGN

2. Filling the missing values.
3. Eliminating the unnecessary features.

## 2.8 Conclusion

### In this chapter, we outlined the methodology used for creating the smart

glove for sign language recognition, covering both software and hardware. The following chapter will delve into the tests and results.

# Chapter 3

# Results and implementation of the

# smart glove

CHAPTER 3. RESULTS AND IMPLEMENTATION OF THE SMART GLOVE

## 3.1 Introduction

### In this last chapter, we highlight the final steps that led us to implment

### the smart glove design in reality and elaborate the crucuial resutls we

reached.

## 3.2 Working environment

### Some software were used to assist in completing the project. The soft-

### ware used include:

### 1. Google Colab : it’s a hosted notebook that gives the access to

### computing ressources[34] , it’s used for training machine and deep

learning models.

Figure 3.1: Google Colab

2. EasyEda: it’s a software for designing and simulating pcb circuits ,

### it has some interesting features including downloading components

### libraries easily by signing up , and there are a lot of contributors to

this platform. We used it to design the PCB.

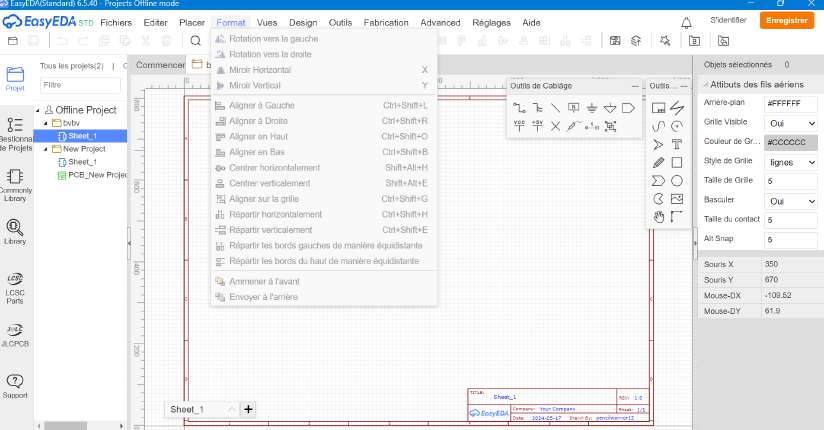
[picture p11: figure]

Figure 3.2: EasyEda

### 3. Raspian OS : the Raspian os is debian-based linux distribution that

### runs on raspberry pi 4 , it’s crucial as it will run the machine model

with all installed libraries in.

### Setting up the raspberry pi 4: An 8GB or larger SD card and

a software tool called Raspberry Imager are required.[35].

### (a) Download raspbian OS iso file and raspberry pi imager from

the official website.

(b) Insert the sd card into the computer.

### (c) Run raspberry pi imager and select the board model and the

### iso file , modify wifi’s setings , login’s information ( username

and password ) and click run.

### (d) Once the process’s finished , insert the sd card into the rasp-

### berry pi board and plug it into the power supply. If you have a

### screen with an HDMI input, you can connect your Raspberry

### Pi to it using an HDMI cable. This will allow you to interact

### with your Raspberry Pi directly if not , connect it to a network

### , install a vnc viewer software on the computer , (both devices

should be connected to the same network ).

### (e) To connect the raspberry pi to the vncviewer , another program

### called Putty is used to establish a ssh connection between the

### board and the laptop, once it’s done , type the command $sudo

raspi-config , enable the vnc feature , and reboot the board.

### (f) Everything is ready , open the vncviewer and type the ip ad-

### dress of the raspberry pi followed by :1

Figure 3.3: Raspberry pi 4 Linux Desktop

### 4. Real vnc viewer : VNC Viewer is used for local computers and

### mobile devices you want to control from[36]. it’s used to control

remotely the raspberry board.

Figure 3.4: RealVnc Viewer

## 3.3 PCB circuit design

### 1. The first thing to do is to design the circuit of the smart glove which

is displayed in the Figure 3.5.

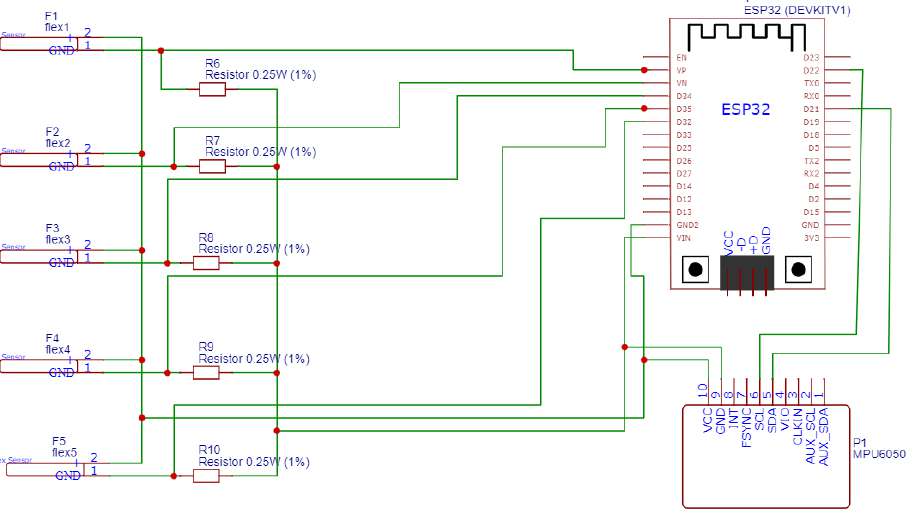
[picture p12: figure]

Figure 3.5: Smart glove’s Schematic

2. After designing the circuit , The schematic was converted to a PCB,

### as shown in the Figures 3.6,3.7. The PCB consists of two layers:

### a copper layer and a components layer as seen in Figures 3.8 and

3.9.

Figure 3.6: EasyEda PCB Design

Figure 3.7: PCB Design result

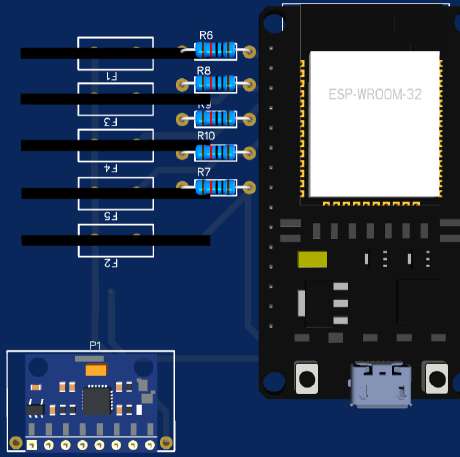
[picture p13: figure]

Figure 3.8: 3D Top view of Double-Sided PCB Prototype

Figure 3.9: 3D bottom View of Double-Sided PCB Prototype

### 3. The circuit design is finished , now , it’s time for soldering compo-

### nents , we couldn’t print a pcb thus , we used a double-sided pcb

### prototype which are shown the Figures 3.11 , 3.12 , 3.10. The

### solder mask is used as an insulator for additional protection and to

prevent oxidation [37]. The mask is treated with UV light.

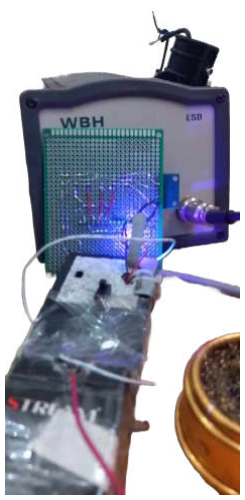
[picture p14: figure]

Figure 3.10: UV Exposure After Applying Solder Mask

Figure 3.11: Top View of
Double-Sided PCB Prototype

Figure 3.12: Bottom View of Double-Sided PCB Prototype

### 4. The flex sensors are attached directly onto the glove using silicone

### including the board too , as a consequence we get a fully smart glove

### with all its necessary components as illustrated in Figure 3.13

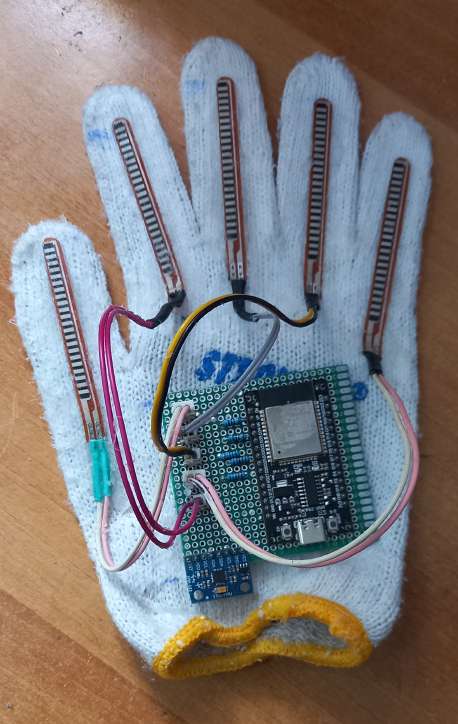
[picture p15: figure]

Figure 3.13: Smart Glove

## 3.4 Sensors Calibration

### Calibrating the sensors is an essential step before using them as it ensures

intact measurements and high precision.

### 3.4.1 Flex sensors calibration

### To calibrate the flex sensors ,The specific library available on the Arduino

### IDE is installed, and here is the complete code for the calibration, shown

### in Figure 3.14:

Figure 3.14: Flex sensors Calibration code

### The analog values of the five flex sensors range between 1073 and

1125 (See Figure 3.15) . Since the ESP32’s ADC channels are 12 bits,

### the voltage between the flex sensors can be calculated as follows:

V =

1073 × 5
2

12 − 1

= 1.31V | (3.1)

Theoretically , the result was 1.17V.

Figure 3.15: Flex sensors calibration results

### 3.4.2 MPU6050 Calibration

### In the case of mpu6050 ,Its accelerometer and gyroscope should be cal-

### ibrated. , but before that , we make sure that the module is working

### and to know that ,The specific library that provides the privilege to read

### both accelerometer and gyroscope data is installed. the code for that is

### shown in Figure 3.16

Figure 3.16: MPU6050 Calibration process

## 3.5 Establishing wireless communication

### As mentioned before , the communication between esp32 and the rasp-

### berry pi 4 is via TCP/IP protocol , there are the following steps to follow

### to achieve it :

### 1. Both devices should be connected to a WI-FI network , to connect

### the esp32 to a WI-FI network , The code shown in Figure 3.17 is

### used:

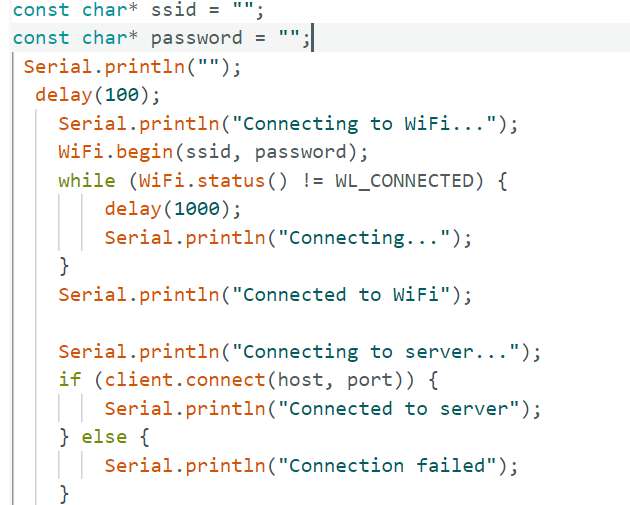
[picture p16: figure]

Figure 3.17: ESP32 WI-Fi connection code

### 2. The sensors data are sent in a binary format , and to do that ,A

### buffer is created and filled with the data, as shown in Figure 3.18:

Figure 3.18: Sensors data processing code

### 3. Since the raspberry pi 4 is already connected to WI-FI ,a Python

### script is created to set up the TCP/IP connection and receive the

### sensor data. The code is shown below in Figure 3.19:

Figure 3.19: Python Code for data reception

### 4. Everything is set up , now , we run both codes , the response is

### represented as seen in Figure 3.20

Figure 3.20: Sensors data reception results

## 3.6 Random forests Model training

### 3.6.1 Training steps

### Our machine learning has been trained for different cases :

1. Training the model for only alphabet.
2. Training the model for only expressions.

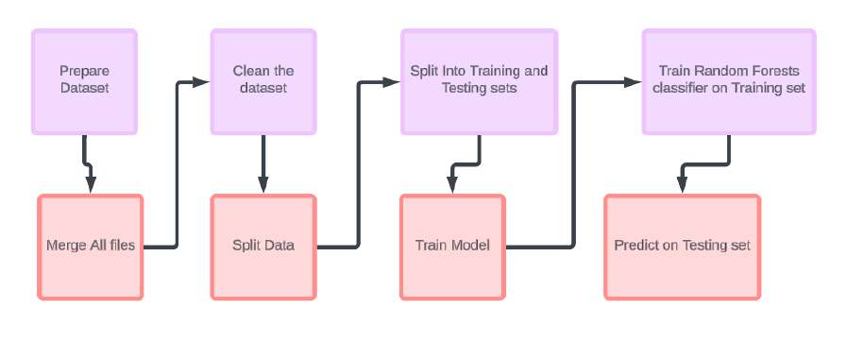
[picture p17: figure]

Figure 3.21: Machine learning Training Process

### 3.6.2 Dataset cleaning process

### As mentioned before , before using the dataset , Data cleaning is neces-

### sary. , in our case ,Negative values were eliminated from the flex sensor

### data. The number of important features is 11. The cleaning is done in

### three steps:

### 1. Merging the csv files : All the datasets should be gathered in one

### file before the training process, as explained in the next code shown

### in Figure 3.22:

Figure 3.22: Python code for merging dataset

### 2. Cleaning the the used dataset: and that includes filling the missing

### values and removing the negative angle values , the process is shown

### in the code above illustrated in Figure 3.23

Figure 3.23: Python code for cleaning dataset

### 3. After that , The unnecessary features are eliminated, leaving 11

### important ones: , and to do that , The Figure 3.23 shows the

code for that.

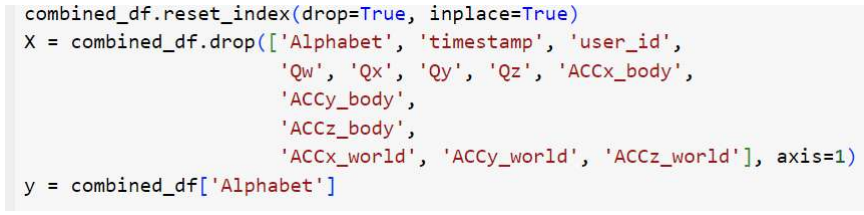
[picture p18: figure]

Figure 3.24: Python code for eliminating unnecessary dataset

### The cleaning process is finished , the results are shown in the table

3.1 :

flex 1 | flex 2 | flex 3 | flex 4 | flex 5 | GYRx | GYRy | GYRz | ACCx | ACCy | ACCz
0 | 46 | 47 | 40 | 37 | -0.022901 | -0.015267 | -0.015267 | 9.380102 | 2.204761 | -0.616089
0 | 47 | 44 | 38 | 35 | -0.022901 | -0.015267 | -0.015267 | 9.347803 | 2.209546 | -0.618481
0 | 47 | 48 | 46 | 33 | -0.015267 | -0.015267 | -0.007634 | 9.317896 | 2.183228 | -0.634033
0 | 48 | 50 | 40 | 33 | -0.015267 | -0.007634 | -0.007634 | 9.326269 | 2.154517 | -0.662744
0 | 47 | 47 | 41 | 36 | -0.007634 | -0.007634 | -0.007634 | 9.34541 | 2.18562 | -0.679492
0 | 45 | 50 | 44 | 36 | -0.007634 | -0.007634 | 0.0 | 9.348999 | 2.228687 | -0.697437
0 | 49 | 46 | 43 | 37 | 0.0 | -0.007634 | 0.0 | 9.353785 | 2.263379 | -0.709399
0 | 51 | 48 | 42 | 38 | -0.007634 | -0.007634 | 0.007634 | 9.363355 | 2.321997 | -0.704614
0 | 48 | 48 | 38 | 35 | -0.015267 | -0.015267 | 0.015267 | 9.369336 | 2.42727 | -0.680689
0 | 52 | 44 | 40 | 37 | -0.022901 | -0.015267 | 0.022901 | 9.374121 | 2.534936 | -0.655566
0 | 49 | 48 | 42 | 37 | -0.022901 | -0.022901 | 0.022901 | 9.386084 | 2.612695 | -0.620874
0 | 49 | 48 | 40 | 35 | -0.022901 | -0.022901 | 0.015267 | 9.392065 | 2.647388 | -0.588574
0 | 48 | 46 | 38 | 33 | -0.015267 | -0.022901 | 0.007634 | 9.414795 | 2.639014 | -0.551489
0 | 49 | 47 | 41 | 35 | -0.015267 | -0.015267 | 0.0 | 9.473413 | 2.604321 | -0.508423
0 | 47 | 47 | 40 | 35 | -0.007634 | -0.015267 | -0.007634 | 9.527246 | 2.558862 | -0.446216
0 | 48 | 47 | 40 | 35 | -0.015267 | -0.022901 | -0.015267 | 9.563135 | 2.511011 | -0.385205

Table 3.1: Dataset pre-processing results

### 4. Scaling the data : and that means fitting the data into a specific

### scale , it’s shown in the Figure 3.25:

Figure 3.25: Python code for data normalisation

## 3.7 Tests and results

### After preparing and normalising the dataset , the next step is training

### the model thus splitting the data into training and testing sets (30% for

### testing , 70% for training) , it’s explained on the Figure 3.26 :

Figure 3.26: Python Code for Splitting Dataset into Training and Testing Sets

### Next, the random forest function is declared without changing its

### default parameters: , The number of trees was randomly set to 600 as

### shown in Figure 3.27

Figure 3.27: Random forests classifier python code

### The last step is to to train the model on the unseen which is the

### testing set as shown in Figure 3.28

Figure 3.28: Python code for generating predictions on Test data

### 3.7.1 Training the model for predicting alphabet

### First, the model is trained without modifying the classifier’s parameters:

### 1. max depth=None

### 2. min samples split=2

### 3. min samples leaf=1

### 4. max samples=None

### 5. max leaf nodes=None

### As results , an accuracy of 99.7% the figure below shows the confusion

### matrix of the trained machine learning model:

Figure 3.29: Alphabet Sign language Confusion Matrix (99% model accuracy)

### 3.7.2 Training the model for predicting expressions

### With the same parameters , The accuracy this time was 98% as it’s

### shown in the figure below :

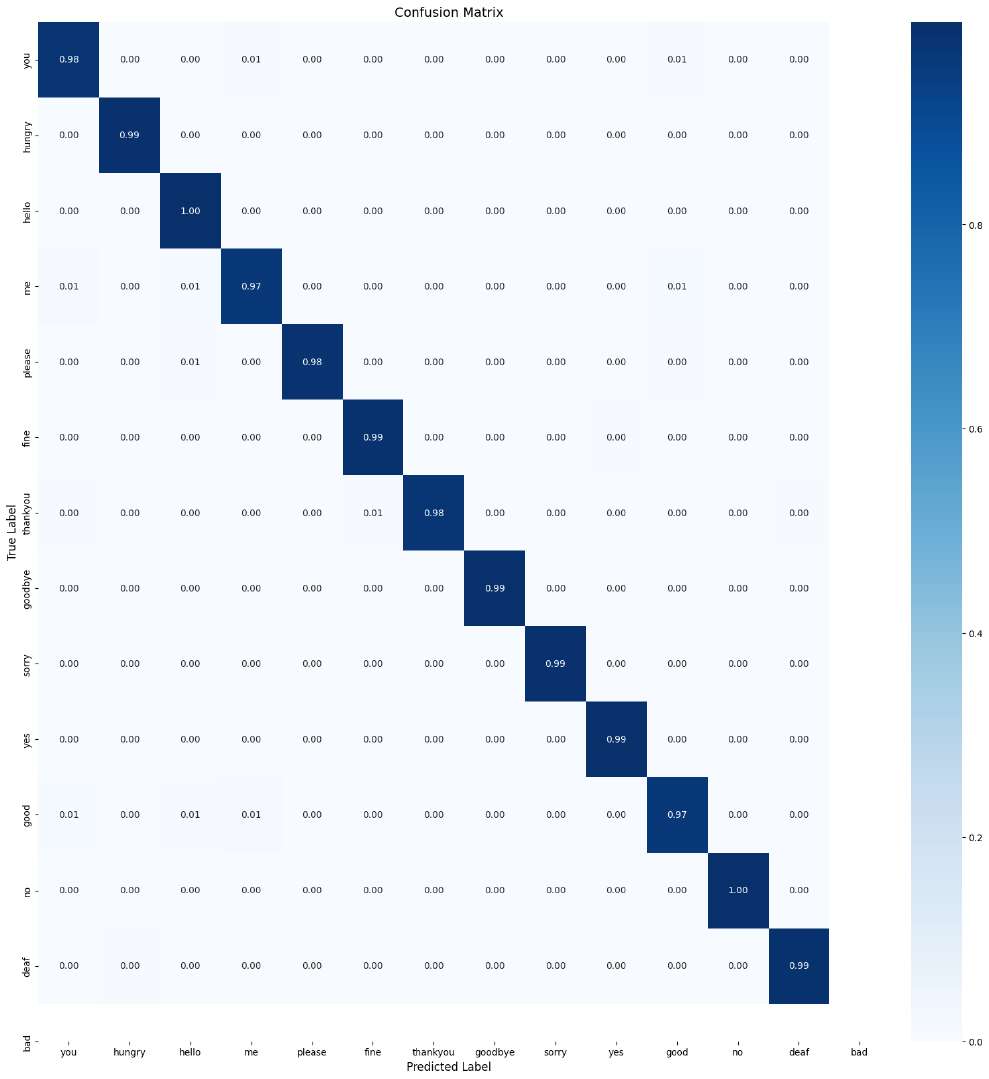
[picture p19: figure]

Figure 3.30: Sign language expressions Confusion Matrix(98% model accuracy)

### Also, the oob score, ROC curve, and accuracy for different numbers

### of trees were calculated, as shown in Figure 3.31 and Figure 3.32:

Figure 3.31: Testing and training accuracy for different number of trees (99% model accuracy)

Figure 3.32: OOB Score for different number of trees(99% model accuracy)

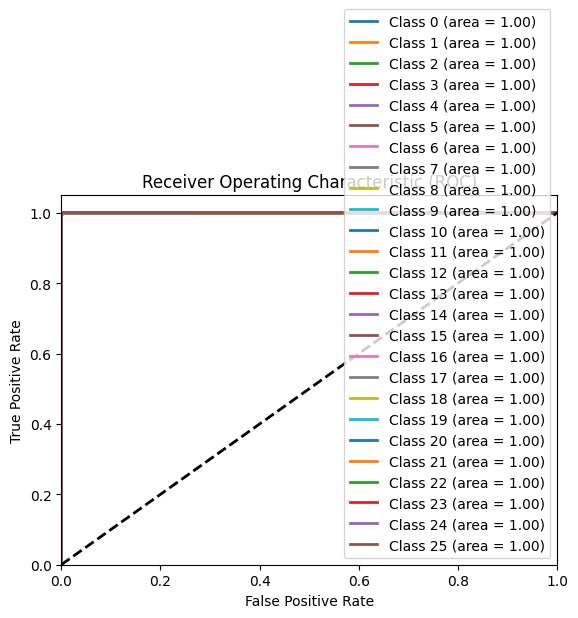
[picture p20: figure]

Figure 3.33: Alphabet sign language ROC curve(99% model accuracy)

### Interpretation: both confusion matrix show a perfect classifica-

### tion for mostly all classes , as the majority of the values lie on the diag-

### onal, indicating that the models predictions match perfectly the actual

### labels. Since there are no misclassifications , it’s considered that both

### models overfit as they memorised prefectly the data and are unable to

generalize well on unseen data.

### The Figure 3.31 shows both training and testing accuracy for dif-

### ferent number of trees. As seen , the model has perfectly learned the

### training dataset as the accuracy becomes 100% changing of oob values

### for different number of trees. The max value is 0.025 and then it de-

### creased to 0.004 while the number of trees becomes 600. That value is

### very small. A value of 0.004 means the model misclassified 0.4% of the

### training data which can explain the perfect results got. In addition to

### that , the changing of number of trees didn’t have an impact on model’s

accuracy.

### In conclusion , it’s clear this model is overfitting thus hypertuning of

the classifier’s parameters needs to be looked forward to.

### 3.7.3 Fine-tuning classifier’s hyperparameters

### the model is trained again with different parameters but with the same

number of trees.

### 1. min samples leaf=5

### 2. max samples = 50

### 3. max depth = 5

### 4. min samples split=4

### 5. max leaf nodes = 150

### The model is trained again for predicting alphabet , and we got an

### accuracy of 82% and an oob score of 0.18 , the Figure 3.35 and Figure

### 3.36 give more details :

Figure 3.34: Alphabet Sign language Confusion Matrix (82% accuracy)

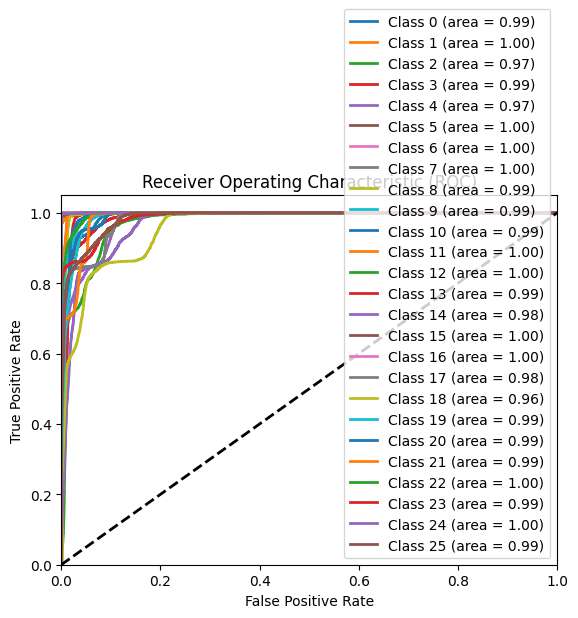
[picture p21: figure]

Figure 3.35: Alphabet sign language ROC curve(82% accuracy)

### The out-of-bag (OOB) score and accuracy for different numbers of

trees were also recalculated, as shown in Figure 3.36 and Figure 3.37.

Figure 3.36: Testing and training accuracy for different number of trees(82% accuracy)

Figure 3.37: OOB Score for different number of trees(82% model accuracy)

### On the other side, only 71% accuracy was achieved when the model

### was trained to predict sign language expressions. Figure 3.38 below

elaborates on the model’s performance.

Figure 3.38: Enter Caption

### Interpretation : This time , both confusion matrix shown in

### Figure 3.34 and Figure 3.38 were affected by the hyperparameters

### changing , as seen, some misclassifications occurred, such as the class

### ”a” being sometimes misclassified. predicted as ”d” (0.15), and ”b” is

### sometimes predicted as ”m” (0.09) , also classes such as g (0.75), ”q”

(0.72), ”w” (0.76), ”s” (0.49) and ”z” (0.45) show lower diagonal values,

### indicating poorer model performance for them. The same case for the

expressions like the class ”me” was predicted sometimes like ”hello”. Some changes in the training and testing accuracy can also be spotted,

### as it’s shown in Figure 3.36 , there’s a slight difference between both

### accuracies but when the number of trees reaches 250, the testing accuracy

### becomes a bit greater than the training accuracy and that means the

model has well generalized predictions on unseen data.

### Interpreting the Figure 3.37 , The oob score was 0.50 and it de-

### creased to 0.15 when the number of trees became 2000 which means the

### model misclassified 15% of the training data , there were an increasing

this time comparing to the first try as it was only 0.4%.

### it can observed that this time , the increasing of number of trees had

### a big influence on model’s accuracy , The Figure 3.39 and Figure

### 3.40 both show how the impact of these estimators when we maintained

### the classifier’s parameters and when they are changed afterwards , The

more trees there are, the greater the accuracy.

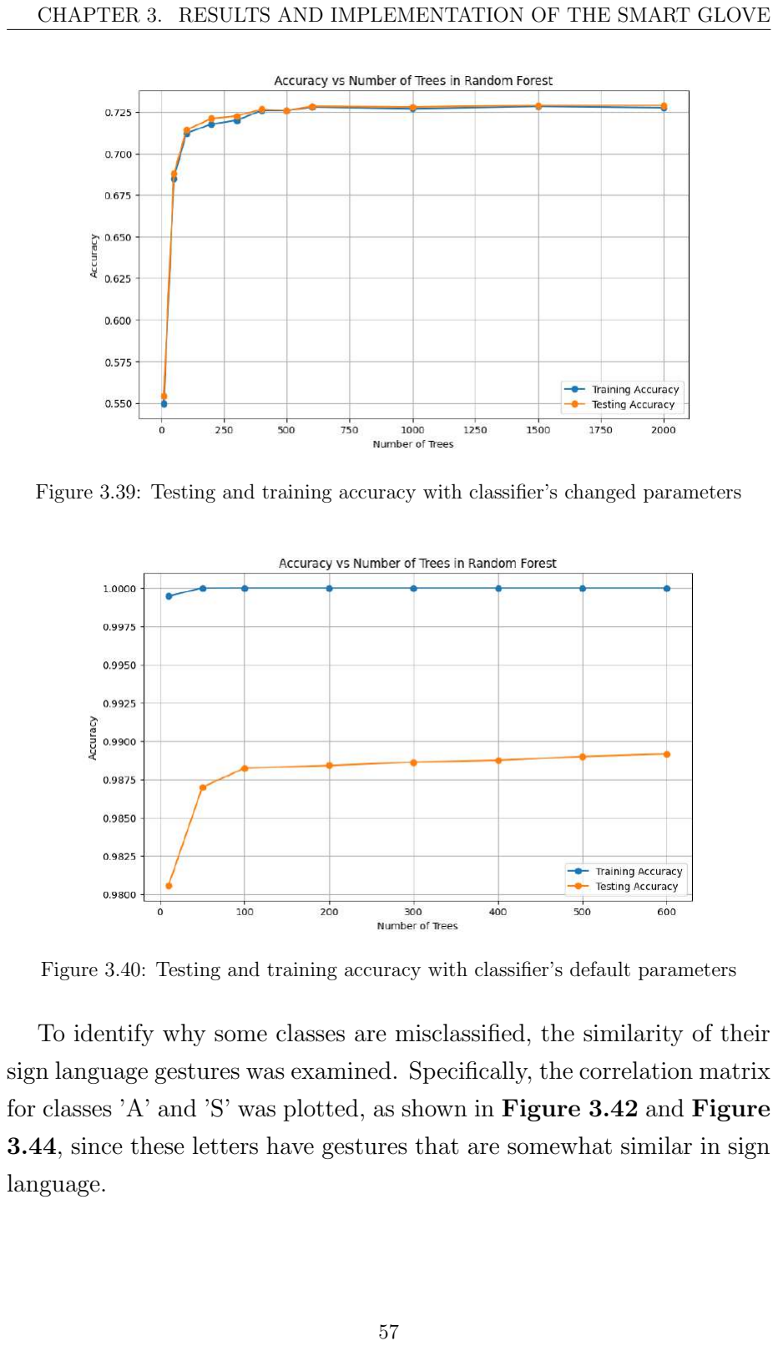
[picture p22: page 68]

Figure 3.39: Testing and training accuracy with classifier’s changed parameters

Figure 3.40: Testing and training accuracy with classifier’s default parameters

### To identify why some classes are misclassified, the similarity of their

### sign language gestures was examined. Specifically, the correlation matrix

### for classes ’A’ and ’S’ was plotted, as shown in Figure 3.42 and Figure

### 3.44, since these letters have gestures that are somewhat similar in sign

language.

Figure 3.41: letter A in sign language

Figure 3.42: correlation plot of the letter A

Figure 3.43: letter S in sign language

Figure 3.44: correlation plot of the letter S

### Interpretation:

### The correlation coefficient in class ’A’ between ’flex 1’ and ’flex 3’ is

### 0.62, suggesting a moderately positive linear association. This indicates

### that ’flex 3’ tends to increase in value in tandem with ’flex 1”s increasing

### value. The correlation coefficient in class ’S’ between ’flex 1’ and ’flex 3’

### is 0.72, suggesting a more robust positive linear link in contrast to class

### ’A’. This indicates that in the sign language gesture for the letter ’S’ as

### opposed to the letter ’A,’ the values of ’flex 1’ and ’flex 3’ are either more

closely related to each other or have a bigger influence on each other.

### In conclusion , it can be concluded that the changing of the classifier’s

### hyperparameters had a positive influence on the model’s performances

### whereas the model struggles to differentiate between the classes that has

somewhat the same gestures.

### To get deeper into the details of how the algorithm work , we intended

### to plot The decisions trees for each model, we choose to plot one tree

### from the first model with 99% accuracy and the second model with 82%

### accuracy as shown in The Figure 3.45 and Figure 3.46

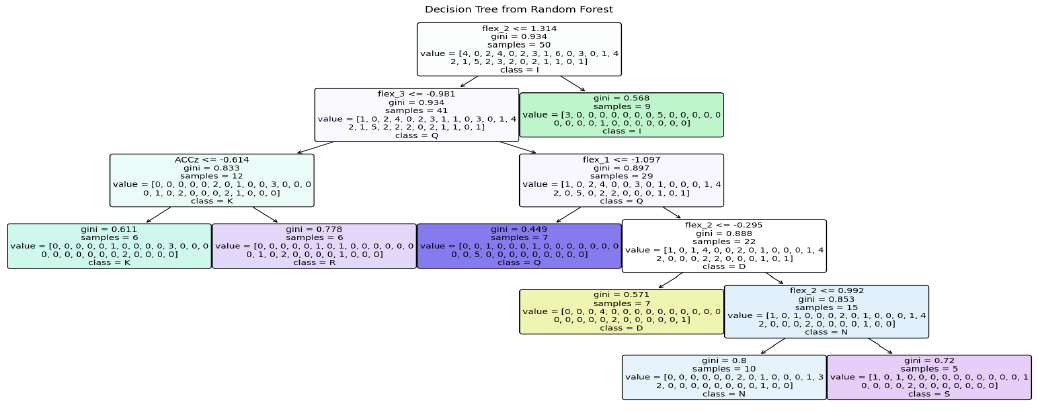
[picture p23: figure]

Figure 3.45: Decision Tree plot (82% accuracy)

CHAPTER 3. RESULTS AND IMPLEMENTATION OF THE SMART GLOVE Figure 3.46: Decision Tree plot (99% accuracy

60

### For the Figure 3.45 , it represents a decision tree from the the second

### model , As seen , the algorithm starts growing the tree with its nodes

### and leaves depending on the parameter ”max depth” which we set it as

### 5 and that means the tree splits 5 times from the root node to the leaf

node.

### The root node starts with a decision based on the feature flex 2 , the

### value 1.314 is the sensor’s threshold. Each node contains:

1. The feature and threshold for the split.
2. The Gini impurity of the node.
3. The number of samples at the node.
4. The distribution of classes at the node (value).
5. The predicted class (class).

### After splitting , the algorithm calculates the number of classes samples

### in each leaf and make preidictions based on the class that has the maxiu-

### mum number of samples. It everytime tries the to decrease the impurity

### until the leaf becomes pure , in our case , it stops when it reaches the

number of trees depth set before.

### For the Figure 3.46 , it’s the same thing but this time , it’s re-

### markable that the tree has many leaves and that’s because the value of

### ”max depth” was set to ”None” which means the tree will keep growing

### leaves until they contain a minimum number of samples which lead most

### of the time to overfitting[24] and that explains the high accuracy of the

model (99%).

### 3.7.4 Classification report

| precision | recall | f1-score | support
you | 0.56 | 0.29 | 0.39 | 3189.00
hungry | 0.78 | 0.91 | 0.84 | 3190.00
hello | 0.49 | 0.89 | 0.63 | 3112.00
me | 0.73 | 0.47 | 0.57 | 3207.00
please | 0.76 | 0.73 | 0.75 | 3179.00
fine | 0.80 | 0.90 | 0.85 | 3144.00
thankyou | 0.75 | 0.57 | 0.65 | 3178.00
goodbye | 0.98 | 0.98 | 0.98 | 3102.00
sorry | 0.60 | 0.92 | 0.73 | 3152.00
yes | 0.92 | 0.88 | 0.90 | 3067.00
good | 0.57 | 0.57 | 0.57 | 3205.00
no | 0.95 | 0.91 | 0.93 | 3207.00
deaf | 0.82 | 0.48 | 0.60 | 3018.00
accuracy | 0.73 | 0.73 | 0.73 | 0.73
macro avg | 0.75 | 0.73 | 0.72 | 40950.00
weighted avg | 0.75 | 0.73 | 0.72 | 40950.00

Table 3.2: sign language expressions Classification report

| precision | recall | f1-score | support
A | 0.74 | 0.89 | 0.81 | 3204.0
B | 0.99 | 0.98 | 0.99 | 3155.0
C | 0.82 | 0.70 | 0.75 | 3227.0
D | 0.66 | 0.97 | 0.78 | 3170.0
E | 0.63 | 0.83 | 0.71 | 3166.0
F | 0.99 | 1.00 | 0.99 | 3122.0
G | 0.86 | 1.00 | 0.93 | 3102.0
H | 1.00 | 1.00 | 1.00 | 3163.0
I | 0.76 | 0.99 | 0.86 | 3068.0
J | 1.00 | 0.67 | 0.80 | 3183.0
K | 0.73 | 0.79 | 0.76 | 3174.0
L | 0.83 | 0.98 | 0.90 | 3072.0
M | 0.87 | 0.93 | 0.90 | 3141.0
N | 0.86 | 0.82 | 0.84 | 3013.0
O | 0.79 | 0.74 | 0.76 | 3182.0
P | 0.99 | 1.00 | 0.99 | 3172.0
Q | 0.85 | 1.00 | 0.92 | 3176.0
R | 0.86 | 0.72 | 0.78 | 3164.0
S | 0.84 | 0.56 | 0.67 | 3198.0
T | 0.96 | 0.57 | 0.71 | 3140.0
U | 0.75 | 0.86 | 0.80 | 3161.0
V | 0.81 | 0.79 | 0.80 | 3234.0
W | 0.98 | 1.00 | 0.99 | 3157.0
X | 0.87 | 0.76 | 0.81 | 3070.0
Y | 0.92 | 1.00 | 0.96 | 3142.0
Z | 0.99 | 0.43 | 0.60 | 3144.0
accuracy | 0.84 | 0.84 | 0.84 | 0.84
macro avg | 0.86 | 0.84 | 0.83 | 81900.0
weighted avg | 0.86 | 0.84 | 0.84 | 81900.0

Table 3.3: sign language alphabet Classification report

### Interpretation : The support values in the tables 3.2 and 3.3

### represent the number of samples for each class, and the slight equality

### among all classes can be determined due to the same number of entries

trained for each class ([38]).

## 3.8 Model Deployment

### The step that comes after the model’s training is deployment which is

### the process of integrating the model into a production environment and

### that’s done in two steps :

### 1. Dumping the model which is saving it in a specific extension , in our

### case , the files are saved as .pkl files that are shown in the Figure

### 3.47 below :

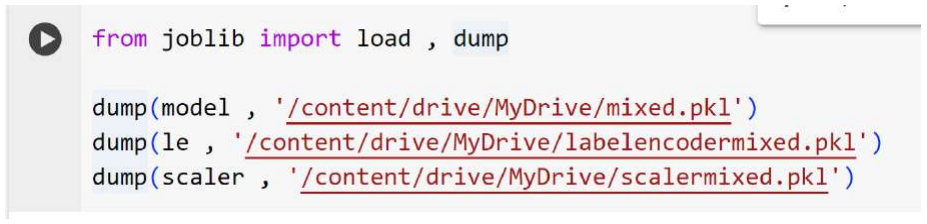
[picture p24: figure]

Figure 3.47: Python Code for Dumping machine learning model

### 2. Loading the model which consists of installing all the necessary

### libraries in the working environment to predict all the classes and

### to load the model , all the files dumped previously need to be loaded

### as shown in Figure 3.48

Figure 3.48: Python Code for loading machine learning model

## 3.9 Conclusion

### In that chapter, we gave details about the results of training the machine

### learning model and calibrating the sensors. We also talked about the

### software used for that as it is crucial to adjusting them to accurately

### record hand movements and gestures. This precision was important too

### for the machine learning model to interpret the data correctly and give

immediate feedback to the user.

### General Conclusion

### This report has elaborated a project that consists of making a smart

### glove that translates ASL to text and speech , that device is a bridge that

### connects the deaf community with the whole society , as it makes it easier

### for them to communicate freely and easier too for the other categories to

### communicate without the need of learning the sign language.Despite this

### , certain limitations exist, one of them is the difficulty to differentiate

between alphabet or expressions that have somewhat the same gesture.

### The first attempt to realise the project was trying I2C communica-

### tion between the smart glove and the raspberry pi 4 as the first one

### is equipped with arduino nano , breadboard and five flex sensors , and

### the mpu6050 is connected directly to the raspberry pi 4. As a part of

### improvements , we attempted to optimise it and making the connection

wiressly using esp32 instead of arduino nano.

### In addition, we faced some challenges when choosing the electronic

### components , as some of the parts weren’t available hence , it was difficult

### to get them. Future improvements The smart glove development

### won’t end up here, as we are dedicated to look up further improvements

### such as :

### 1. Implementing another machine or deep learning models for algerian

### sign language classification trained with a dataset that should be

collected by us.

2. Improving the real time accuracy.

### 3. Developing a mobile application to make it easier for the deaf com-

munity to interact within the society.

### The dataset used for training and testing the model can be accessed at

https://figshare.com/articles/dataset/ASL-Sensor-Dataglove-Dataset_

zip/20031017. (https://figshare.com/articles/dataset/ASL-Sensor-Dataglove-Dataset_zip/20031017)

# Bibliography

[1] R Jayanthi et al. “Empowering Independence: A Smart Glove for Gesture-Based Navigation of Physically Challenged Individuals with Arduino Technology”. en. In: 05.05 (2023).
[2] Muhammad Rifki Kurniawan, Ahmad Hasibul Hadi, and Siska Novitasari. “A Smart Glove for Sign Language Translation”. In: Proceedings of the 2017 International Conference on Advanced Computer Science and Information Systems (ICACSIS). IEEE. 2017, pp. 303–308.
[3] K. P. Sruthi et al. “Smart Glove with Sensor Integration for the Deaf and Dumb”. In: Journal of Emerging Technologies and Innovative Research 6.4 (2019), pp. 589– 594.
[4] Neven Saleh et al. “Smart glove-based gestures recognition system for Arabic sign language”. en. In: 2020 International Conference on Innovative Trends in Communication and Computer Engineering (ITCE). Aswan, Egypt: IEEE, Feb. 2020, pp. 303–307. isbn: 978-1-72814-801-4. doi: 10.1109/ITCE48509.2020. 9047820. (https://doi.org/10.1109/ITCE48509.2020.9047820) url: https://ieeexplore.ieee.org/document/9047820/.
[5] Sawant Pramada. “Intelligent Sign Language Recognition Using Image Processing”. en. In: IOSR Journal of Engineering 03.02 (Feb. 2013), pp. 45–51. issn: 22788719, 22503021. doi: 10.9790/3021-03224551. (https://doi.org/10.9790/3021-03224551)
[6] About Her. 8 Things To Know About Hadeel Ayoub, Saudi Arabian Inventor of The Smart Glove. Accessed: 2024-06-13. 2019. url: https://www.abouther.

com/node/21376/people/leading-ladies/8-things-know-about-hadeelayoub-saudi-arabian-inventor-smart-glove. (https://www.abouther.com/node/21376/people/leading-ladies/8-things-know-about-hadeel-ayoub-saudi-arabian-inventor-smart-glove)

[7] V7 Labs. “Supervised vs. Unsupervised Learning [Differences & Examples]”. In: (2023). url: https://www.v7labs.com/blog/supervised-vs-unsupervised-

learning. (https://www.v7labs.com/blog/supervised-vs-unsupervised-learning)

[8] DatabaseTown. “Unsupervised Learning: Types, Applications & Advantages”. In: (2023). url: https://databasetown.com/unsupervised- learning- types-

applications/. (https://databasetown.com/unsupervised-learning-types-applications/)

[9] IBM. What is a Neural Network? https : / / www . ibm . com / topics / neural -

networks. (https://www.ibm.com/topics/neural-networks) 2023.

[10] GeeksforGeeks. “Support Vector Machine Algorithm”. In: (2023). url: https:

//www.geeksforgeeks.org/support-vector-machine-algorithm/.

[11] Leo Breiman. “Random forests”. In: Machine learning 45.1 (2001), pp. 5–32.
[12] Raspberry Pi 4 Model B Specifications. https : / / www . raspberrypi . com /

products/raspberry-pi-4-model-b/specifications/. (https://www.raspberrypi.com/products/raspberry-pi-4-model-b/specifications/) Accessed: Insert date accessed.

[13] Espressif Systems. ESP32 Microcontroller Description. Internal Documentation. Accessed: Insert date accessed. Year of Publication.
[14] SparkFun Electronics. Flex Sensor Special Edition Datasheet. https : / / cdn .

sparkfun.com/assets/9/5/b/f/7/FLEX_SENSOR_-_SPECIAL_EDITION_DATA_ SHEET_v2019__Rev_A_.pdf. (https://cdn.sparkfun.com/assets/9/5/b/f/7/FLEX_SENSOR_-_SPECIAL_EDITION_DATA_SHEET_v2019__Rev_A_.pdf) Accessed: Insert date accessed.

[15] MPU-6050. Accessed: June 19, 2024. TDK InvenSense. url: https://invensense.

tdk.com/products/motion-tracking/6-axis/mpu-6050/%5C#:%5C~:text= The%5C%20MPU-D6050%5C%20devices%5C%20combine. (https://invensense.tdk.com/products/motion-tracking/6-axis/mpu-6050/%5C)

[16] James Montantes. 3 reasons to use random forest over a neural network–comparing machine learning versus deep... Apr. 2024. url: https://towardsdatascience.

com/3-reasons-to-use-random-forest-over-a-neural-network-comparingmachine-learning-versus-deep-f9d65a154d89. (https://towardsdatascience.com/3-reasons-to-use-random-forest-over-a-neural-network-comparing-machine-learning-versus-deep-f9d65a154d89)

[17] E R Sruthi. Random Forest — Introduction to Random Forest Algorithm. June

2021. url: https://www.analyticsvidhya.com/blog/2021/06/understandingrandom-forest/. (https://www.analyticsvidhya.com/blog/2021/06/understanding-random-forest/)

[18] Sruthi E. R. Understand Random Forest Algorithm With Examples (Updated 2024). June 2021. url: https : / / www . analyticsvidhya . com / blog / 2021 /

06 / understanding - random - forest / # : ~ : text = Random % 20forest % 20is % 20highly%20complex. (https://www.analyticsvidhya.com/blog/2021/06/understanding-random-forest/)

[19] Adam Pantanowitz and Tshilidzi Marwala. “Missing Data Imputation Through the Use of the Random Forest Algorithm”. en. In: Advances in Computational Intelligence. Ed. by Wen Yu and Edgar N. Sanchez. Vol. 116. Advances in Intelligent and Soft Computing. Berlin, Heidelberg: Springer Berlin Heidelberg, 2009, pp. 53–62. isbn: 978-3-642-03155-7. doi: 10.1007/978-3-642-03156-4_6. (https://doi.org/10.1007/978-3-642-03156-4_6) url: http://link.springer.com/10.1007/978-3-642-03156-4_6.
[20] L´eo Grinsztajn, Edouard Oyallon, and Ga¨el Varoquaux. “Why do tree-based models still outperform deep learning on typical tabular data?” en. In: ().
[21] Last Minute Engineers. In-Depth: Interfacing Flex Sensor with Arduino. https:

/ / lastminuteengineers . com / flex - sensor - arduino - tutorial / #google _ vignette. (https://lastminuteengineers.com/flex-sensor-arduino-tutorial/#google_vignette) Apr. 2020.

[22] Jobit Joseph. How Does the MPU6050 Accelerometer & Gyroscope Sensor Work and Interfacing It With Arduino. May 2022. url: https://circuitdigest.com/

microcontroller-projects/interfacing-mpu6050-module-with-arduino. (https://circuitdigest.com/microcontroller-projects/interfacing-mpu6050-module-with-arduino)

[23] TCP/IP server on an ESP32. 2023. url: https://forum.arduino.cc/t/tc-

ip-server-on-an-esp32/1140930/4. (https://forum.arduino.cc/t/tc-ip-server-on-an-esp32/1140930/4)

[24] GeeksforGeeks. Hyperparameters of Random Forest Classifier. https : / / www .

geeksforgeeks . org / hyperparameters - of - random - forest - classifier/. (https://www.geeksforgeeks.org/hyperparameters-of-random-forest-classifier/) Jan. 2021.

[25] Navnina Bhatia. What is Out of Bag (OOB) score in Random Forest? June 2019.

url: https://towardsdatascience.com/what-is-out-of-bag-oob-scorein-random-forest-a7fa23d710. (https://towardsdatascience.com/what-is-out-of-bag-oob-score-in-random-forest-a7fa23d710)

[26] Noam Bressler. How to Check the Accuracy of Your Machine Learning Model.

Nov. 2021. url: https://deepchecks.com/how-to-check-the-accuracy-ofyour-machine-learning-model/. (https://deepchecks.com/how-to-check-the-accuracy-of-your-machine-learning-model/)

[27] Google Developers. Classification: Precision and Recall — Machine Learning

Crash Course — Google Developers. https://developers.google.com/machinelearning / crash - course / classification / precision - and - recall. (https://developers.google.com/machine-learning/crash-course/classification/precision-and-recall) Mar. 2019.

[28] Google. Classification: ROC Curve and AUC — Machine Learning Crash

Course. 2019. url: https://developers.google.com/machine- learning/ crash-course/classification/roc-and-auc. (https://developers.google.com/machine-learning/crash-course/classification/roc-and-auc)

[29] Rohit Kundu. Confusion Matrix: How To Use It & Interpret Results [Examples].

Sept. 2022. url: https://www.v7labs.com/blog/confusion-matrix-guide.

[30] scikit-learn. sklearn.metrics.f1score|scikit−learn0.21.2documentation. 2019. url:

https://scikit-learn.org/stable/modules/generated/sklearn.metrics.f1_score.html. (https://scikit-learn.org/stable/modules/generated/sklearn.metrics.f1_score.html)

[31] Sanskar Wagavkar. Introduction to The Correlation Matrix. Mar. 2023. url:

https : / / builtin . com / data - science / correlation - matrix# : ~ : text = Shutterstock%20%2F%20Built%20In-. (https://builtin.com/data-science/correlation-matrix#:~:text=Shutterstock%20%2F%20Built%20In-)

[32] GeeksforGeeks. Create a correlation matrix using Python. https://www.geeksforgeeks.

org/create-a-correlation-matrix-using-python/. (https://www.geeksforgeeks.org/create-a-correlation-matrix-using-python/) Nov. 2020.

[33] Md. Ahasan Atick Faisal. “DU-ASL-DATA-GLOVE-DB”. In: (June 2022). doi:

10.6084/m9.figshare.20031017.v2. (https://doi.org/10.6084/m9.figshare.20031017.v2) url: https://figshare.com/articles/dataset/ASL-Sensor-Dataglove-Dataset_zip/20031017. (https://figshare.com/articles/dataset/ASL-Sensor-Dataglove-Dataset_zip/20031017)

[34] url: https://colab.google/.
[35] Raspberry Pi Documentation - Getting Started. https : / / www . raspberrypi .

com/documentation/computers/getting-started.html. (https://www.raspberrypi.com/documentation/computers/getting-started.html)

[36] RealVNC® Ltd. All you need to know about VNC remote access technology.

url: https : / / discover . realvnc . com / what - is - vnc - remote - access -technology#:~:text=VNC%20Viewer%20is%20used%20for. (https://discover.realvnc.com/what-is-vnc-remote-access-technology)

[37] Bittele Electronics. How Important are Solder Masks and Silkscreens. https :

//www.7pcb.com/blog/how-important-are-solder-masks-silkscreens.

[38] The scikit-developers. Classification Report — Yellowbrick v1.5 documentation.

url: https://www.scikit-yb.org/en/latest/api/classifier/classification_report.html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. (https://www.scikit-yb.org/en/latest/api/classifier/classification_report.html)

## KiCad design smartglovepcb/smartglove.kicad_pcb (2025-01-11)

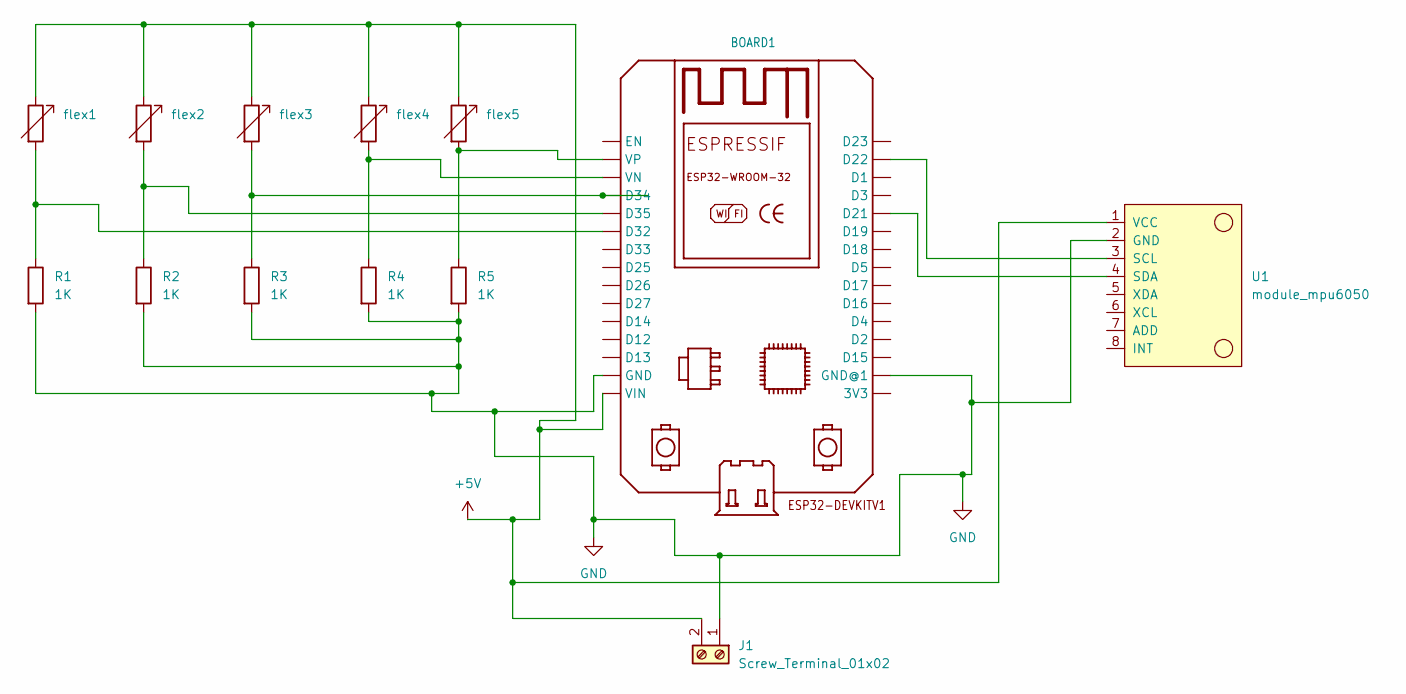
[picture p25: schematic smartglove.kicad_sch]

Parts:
BOARD1: ESP32-DEVKITV1
J1: Screw_Terminal_01x02; screwterminal
R1, R2, R3, R4, R5: 1K; R_Axial_DIN0207_L6.3mm_D2.5mm_P7.62mm_Horizontal
U1: module_mpu6050
flex1, flex2, flex3, flex4, flex5: R_Variable; JST_EH_B2B-EH-A_1x02_P2.50mm_Vertical

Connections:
+5V: BOARD1.VIN, J1.2, flex1.1, flex2.1, flex3.1, flex4.1, flex5.1; also elsewhere on the board
GND: BOARD1.GND, BOARD1.GND@1, J1.1, R1.2, R2.2, R3.2, R4.2, R5.2; also elsewhere on the board
unnamed: BOARD1.D32, R1.1, flex1.2
unnamed: BOARD1.D34, R3.1, flex3.2
unnamed: BOARD1.D35, R2.1, flex2.2
unnamed: BOARD1.VN, R4.1, flex4.2
unnamed: BOARD1.VP, R5.1, flex5.2
unnamed 7: BOARD1.D22; also elsewhere on the board
unnamed 8: BOARD1.D21; also elsewhere on the board

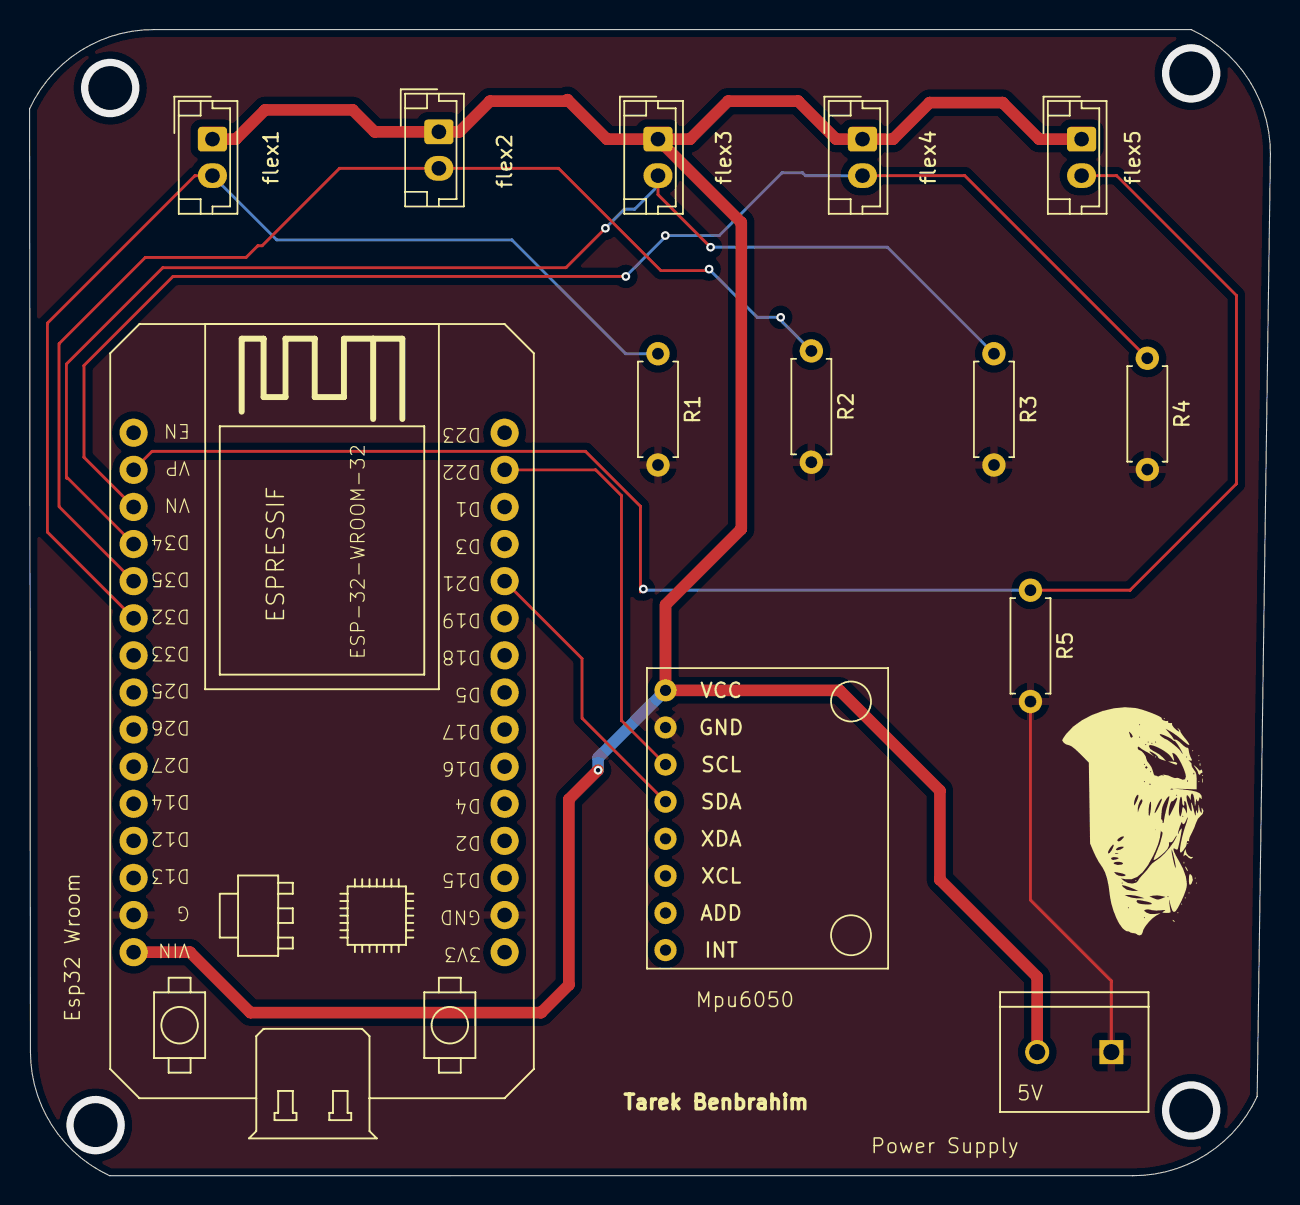
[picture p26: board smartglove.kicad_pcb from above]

Board: 2 copper layers, 84.9 x 78.5 mm, 13 parts (0 on the bottom side), 9 nets.

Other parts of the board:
U2: module_mpu6050

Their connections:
+5V: U2.1 (VCC); also elsewhere on the board
GND: U2.2 (GND); also elsewhere on the board
unnamed 7: U2.3 (SCL); also elsewhere on the board
unnamed 8: U2.4 (SDA); also elsewhere on the board

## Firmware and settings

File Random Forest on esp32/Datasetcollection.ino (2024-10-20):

#include "FlexLibrary.h"
#include <Adafruit_MPU6050.h>
#include <Adafruit_Sensor.h>
#include <Wire.h>
Flex flex[5] = {Flex(36), Flex(39), Flex(34), Flex(35), Flex(32)}; // Analog pins the flex sensors are on
Adafruit_MPU6050 mpu;

               
void setup() {
    Serial.begin(9600);
    while (!Serial)
    delay(10); // will pause Zero, Leonardo, etc until serial console opens

  Serial.println("Adafruit MPU6050 test!");

  // Try to initialize!
  if (!mpu.begin()) {
    Serial.println("Failed to find MPU6050 chip");
    while (1) {
      delay(10);
    }
  }
  Serial.println("MPU6050 Found!");

     mpu.setAccelerometerRange(MPU6050_RANGE_8_G);
  Serial.print("Accelerometer range set to: ");
  switch (mpu.getAccelerometerRange()) {
  case MPU6050_RANGE_2_G:
    Serial.println("+-2G");
    break;
  case MPU6050_RANGE_4_G:
    Serial.println("+-4G");
    break;
  case MPU6050_RANGE_8_G:
    Serial.println("+-8G");
    break;
  case MPU6050_RANGE_16_G:
    Serial.println("+-16G");
    break;
  }
  mpu.setGyroRange(MPU6050_RANGE_500_DEG);
  Serial.print("Gyro range set to: ");
  switch (mpu.getGyroRange()) {
  case MPU6050_RANGE_250_DEG:
    Serial.println("+- 250 deg/s");
    break;
  case MPU6050_RANGE_500_DEG:
    Serial.println("+- 500 deg/s");
    break;
  case MPU6050_RANGE_1000_DEG:
    Serial.println("+- 1000 deg/s");
    break;
  case MPU6050_RANGE_2000_DEG:
    Serial.println("+- 2000 deg/s");
    break;
  }

  mpu.setFilterBandwidth(MPU6050_BAND_21_HZ);
  Serial.print("Filter bandwidth set to: ");
  switch (mpu.getFilterBandwidth()) {
  case MPU6050_BAND_260_HZ:
    Serial.println("260 Hz");
    break;
  case MPU6050_BAND_184_HZ:
    Serial.println("184 Hz");
    break;
  case MPU6050_BAND_94_HZ:
    Serial.println("94 Hz");
    break;
  case MPU6050_BAND_44_HZ:
    Serial.println("44 Hz");
    break;
  case MPU6050_BAND_21_HZ:
    Serial.println("21 Hz");
    break;
  case MPU6050_BAND_10_HZ:
    Serial.println("10 Hz");
    break;
  case MPU6050_BAND_5_HZ:
    Serial.println("5 Hz");
    break;
  }}
void loop() {
    sensors_event_t a, g, temp;  // To store MPU6050 data
    mpu.getEvent(&a, &g, &temp);  // Get MPU6050 data (accelerometer, gyroscope, temperature)
    
    // Print flex sensor values
    for (int i = 0; i < 5; i++) {
        flex[i].updateVal();  // Update flex sensor value
        Serial.print(flex[i].getSensorValue());  // Print flex sensor raw value
        if (i < 4) {
            Serial.print(", ");  // Add comma between values
        }
    }

    // Print MPU6050 Gyroscope data
    Serial.print(", ");
    Serial.print(g.gyro.x);
    Serial.print(", ");
    Serial.print(g.gyro.y);
    Serial.print(", ");
    Serial.print(g.gyro.z);

    // Print MPU6050 Accelerometer data

    Serial.print(", ");
    Serial.print(a.acceleration.x);
    Serial.print(", ");
    Serial.print(a.acceleration.y);
    Serial.print(", ");
    Serial.print(a.acceleration.z);

    // New line after printing all data
    Serial.println();

    // Delay for a second
    delay(1000); 
}

               

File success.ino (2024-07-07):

#include <WiFi.h>
#include "FlexLibrary.h"
#include <Adafruit_MPU6050.h>
#include <Adafruit_Sensor.h>
#include <Wire.h>
#define VCC 5.0// Voltage supplied to the flex sensors
#define R_DIV 10000.0  // Resistance of the resistor in series with the flex sensors
#define flatResistance 32500.0  // Resistance of the flex sensors when flat
#define bendResistance 76000.0  // Resistance of the flex sensors when bent

Flex flex[5] = {Flex(36), Flex(39), Flex(34), Flex(35), Flex(32)}; // Analog pins the flex sensors are on


const char* ssid = "";
const char* password = "";
const char* host ="";  // Raspberry Pi IP address
const int port = 4444;

WiFiClient client;
Adafruit_MPU6050 mpu;

void setup() {
    Serial.begin(9600);
    while (!Serial)
    delay(10); // will pause Zero, Leonardo, etc until serial console opens

  Serial.println("Adafruit MPU6050 test!");

  // Try to initialize!
  if (!mpu.begin()) {
    Serial.println("Failed to find MPU6050 chip");
    while (1) {
      delay(10);
    }
  }
  Serial.println("MPU6050 Found!");

     mpu.setAccelerometerRange(MPU6050_RANGE_8_G);
  Serial.print("Accelerometer range set to: ");
  switch (mpu.getAccelerometerRange()) {
  case MPU6050_RANGE_2_G:
    Serial.println("+-2G");
    break;
  case MPU6050_RANGE_4_G:
    Serial.println("+-4G");
    break;
  case MPU6050_RANGE_8_G:
    Serial.println("+-8G");
    break;
  case MPU6050_RANGE_16_G:
    Serial.println("+-16G");
    break;
  }
  mpu.setGyroRange(MPU6050_RANGE_500_DEG);
  Serial.print("Gyro range set to: ");
  switch (mpu.getGyroRange()) {
  case MPU6050_RANGE_250_DEG:
    Serial.println("+- 250 deg/s");
    break;
  case MPU6050_RANGE_500_DEG:
    Serial.println("+- 500 deg/s");
    break;
  case MPU6050_RANGE_1000_DEG:
    Serial.println("+- 1000 deg/s");
    break;
  case MPU6050_RANGE_2000_DEG:
    Serial.println("+- 2000 deg/s");
    break;
  }

  mpu.setFilterBandwidth(MPU6050_BAND_21_HZ);
  Serial.print("Filter bandwidth set to: ");
  switch (mpu.getFilterBandwidth()) {
  case MPU6050_BAND_260_HZ:
    Serial.println("260 Hz");
    break;
  case MPU6050_BAND_184_HZ:
    Serial.println("184 Hz");
    break;
  case MPU6050_BAND_94_HZ:
    Serial.println("94 Hz");
    break;
  case MPU6050_BAND_44_HZ:
    Serial.println("44 Hz");
    break;
  case MPU6050_BAND_21_HZ:
    Serial.println("21 Hz");
    break;
  case MPU6050_BAND_10_HZ:
    Serial.println("10 Hz");
    break;
  case MPU6050_BAND_5_HZ:
    Serial.println("5 Hz");
    break;
  }

  Serial.println("");
  delay(100);
    Serial.println("Connecting to WiFi...");
    WiFi.begin(ssid, password);
    while (WiFi.status() != WL_CONNECTED) {
        delay(1000);
        Serial.println("Connecting...");
    }
    Serial.println("Connected to WiFi");

    Serial.println("Connecting to server...");
    if (client.connect(host, port)) {
        Serial.println("Connected to server");
    } else {
        Serial.println("Connection failed");
    }

    
}
void loop() {
    float angles[5];
    sensors_event_t a, g, temp;
    mpu.getEvent(&a, &g, &temp);

    for (int i = 0; i < 5; i++) {
        for(int j = 0; j < 1000; j++){
        flex[i].Calibrate();
  }
        flex[i].updateVal();
       
        float Vflex = flex[i].getSensorValue() * VCC / 4095.0;
        float Rflex = R_DIV * (VCC / Vflex - 1.0);

        angles[i] = map(Rflex, flatResistance, bendResistance, 0, 90);
        if(angles[i]<0){
          angles[i]=0;
        }
       // Serial.println(angles[i]);
    }


    byte data[sizeof(float) * 5 + sizeof(float) * 3 + sizeof(float) * 3];

  
    memcpy(data, angles, sizeof(float) * 5);

    
    memcpy(data + sizeof(float) * 8, &g.gyro.x, sizeof(float));
    memcpy(data + sizeof(float) * 9, &g.gyro.y, sizeof(float));
    memcpy(data + sizeof(float) * 10, &g.gyro.z, sizeof(float));
    memcpy(data + sizeof(float) * 5, &a.acceleration.x, sizeof(float));
    memcpy(data + sizeof(float) * 6, &a.acceleration.y, sizeof(float));
    memcpy(data + sizeof(float) * 7, &a.acceleration.z, sizeof(float));
   

    if (client.connected()) {
        client.write(data, sizeof(data));
    } else {
        Serial.println("Connection to server lost. Reconnecting...");
        if (client.connect(host, port)) {
            Serial.println("Reconnected to server");
            client.write(data, sizeof(data));
        } else {
            Serial.println("Reconnection failed");
        }
    }
/*Serial.print(g.gyro.x);
Serial.print("\n");
Serial.print(g.gyro.x);
Serial.print("\n");
Serial.print(g.gyro.x);
Serial.print("\n");
Serial.print(a.acceleration.x);
Serial.print("\n");
Serial.print(a.acceleration.y);
Serial.print("\n");
Serial.print(a.acceleration.z);
Serial.print("\n");*/
    delay(1000);  // Adjust delay as needed
}
